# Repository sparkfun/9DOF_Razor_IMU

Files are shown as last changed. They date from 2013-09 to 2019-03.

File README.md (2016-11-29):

SparkFun 9DoF Razor IMU M0
========================================

SparkFun 9DoF Razor IMU M0 (https://www.sparkfun.com/products/14001)

[*SparkFun 9DoF Razor IMU M0 (SEN-14001)*](https://www.sparkfun.com/products/14001)

The [SparkFun 9DoF Razor IMU M0](https://www.sparkfun.com/products/14001) combines a [SAMD21](https://www.sparkfun.com/products/13664) microprocessor with an [MPU-9250](https://www.sparkfun.com/products/13762) 9DoF (nine degrees of freedom) sensor to create a tiny, re-programmable, multi-purpose inertial measurement unit (IMU). It can be programmed to monitor and log motion, transmit Euler angles over a serial port, or to even act as a step-counting pedometer.

The 9DoF Razor's MPU-9250 features three, three-axis sensors -- an accelerometer, gyroscope, and magnetometer -- which gives it the ability to sense linear acceleration, angular rotation velocity, and magnetic field vector's. The on-board microprocessor -- Atmel's [SAMD21G18A](http://www.atmel.com/devices/ATSAMD21G18.aspx) -- is an Arduino-compatible, 32-bit ARM Cortex-M0+ microcontroller also featured on the [Arduino Zero](https://www.arduino.cc/en/Main/ArduinoBoardZero) and [SAMD21 Mini Breakout](https://www.sparkfun.com/products/13664) boards.

Repository Contents
-------------------

* **/Documentation** - Data sheets, additional product information
* **/Firmware** - Example code 
* **/Hardware** - Eagle design files (.brd, .sch)
* **/Libraries** - Libraries for use with the 9DoF Razor IMU M0
* **/Production Files** - Production panel files (.brd)

Documentation
--------------
* **[SparkFun MPU-9250 DMP Arduino Library](https://github.com/sparkfun/SparkFun_MPU-9250-DMP_Arduino_Library)** - Arduino library for the 9DoF Razor IMU M0's MPU-9250, enabling the 9DoF's digital motion processor (DMP).
* **[Hookup Guide](https://learn.sparkfun.com/tutorials/9dof-razor-imu-m0-hookup-guide)** - Basic hookup guide for the 9DoF Razor IMU M0.
* **[SparkFun Fritzing repo](https://github.com/sparkfun/Fritzing_Parts)** - Fritzing diagrams for SparkFun products.
* **[SparkFun 3D Model repo](https://github.com/sparkfun/3D_Models)** - 3D models of SparkFun products. 

Product Versions
----------------
* [SparkFun 9DoF Razor IMU M0 (SEN-14001)](https://www.sparkfun.com/products/14001)- Latest release.
* [SparkFun 9DoF Razor IMU (SEN-10736)](https://www.sparkfun.com/products/retired/10736) - Initial release, featuring an ATmega328, ADXL345 (accelerometer), ITG-3200 (gyroscope), and HMC5883L (magnetometer).

Version History
---------------
* [V_3.0](https://github.com/sparkfun/9DOF_Razor_IMU/releases/tag/V_3.0) - Hardware and firmware files for version 3.0 -- released as SEN-14001.
* [V_2.3](https://github.com/sparkfun/9DOF_Razor_IMU/releases/tag/V_2.3) - Hardware and firmware design files for version 2.3 -- released as SEN-10736.

License Information
-------------------

This product is _**open source**_! 

Please review the LICENSE.md file for license information. 

If you have any questions or concerns on licensing, please contact techsupport@sparkfun.com.

Distributed as-is; no warranty is given.

- Your friends at SparkFun.

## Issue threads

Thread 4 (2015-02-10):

v23 Firmware Crashing on As-Delivered Razor

gdevenyi, 2015-02-10:
I just wired up my razor and turned it on, the menu shows up, and I can interact with it, the magnometer and the gyro work properly (print out measurements), however, if I try and trigger the Accelerometer output, the device crashes:

```
9DOF IMU Firmware v23
==========================
[1]Accelerometer: ADXL345
[2]Magnetometer: HMC5883
[3]Gyroscope: ITG-3200
[4]Raw Output
[5]Change Baud Rate: 57600bps
[Ctrl+z]Toggle Autorun
[?]Help
<PRESSED 1>

x=-22772, y= -28, ITG: GOOD
HMC: GOOD
ADXL: GOOD

9DOF IMU Firmware v23
==========================
[1]Accelerometer: ADXL345
[2]Magnetometer: HMC5883
[3]Gyroscope: ITG-3200
[4]Raw Output
[5]Change Baud Rate: 57600bps
[Ctrl+z]Toggle Autorun
[?]Help
```

This cycle is accompanied by the LEDs doing their "4 blinks and off" for "good"

ToniCorinne, 2015-02-13:
Hey there - sorry to hear about this problem. It sounds like this might be more hardware based, so please contact our tech support team at techsupport@sparkfun.com. They should be able to help you out with the hardware fix easier than we could do on GitHub (and get you a replacement if needed :) ).

gdevenyi, 2015-02-13:
In a email thread with them too. Thanks.

gdevenyi, 2019-02-18:
Defective device replaced.

Closed 2019-02-18.

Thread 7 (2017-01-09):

samd21_sam_ba.atsln file not existing in the repository

lunarpulse, 2017-01-09:
I have tried to compile and learn from the firmware. However, the repository does not have the solution file for Atmel studio. In addition, there are some errors while compiling without the solution file.

First: non existing member of the volatile structures of U

Error		'volatile struct <anonymous>' has no member named 'TRCPT' at 9dof_bootloader_sparkfun\board_driver_usb.c	176	52	Build

Error		'volatile struct <anonymous>' has no member named 'STALLRQ'	\9dof_bootloader_sparkfun\board_driver_usb.c	307	51	Build

Both of them are located in USB_DEVICE_EPINTFLAG_Type struct in usb.h. But the compiler could not find.

I guess these compilation issues may be caused by the absence of the samd21_sam_ba.atsln file or other absent files which contain the right configuration for the compilation.

Furthermore, could you guide me how to correctly compile this in Atmel studio?

lunarpulse, 2017-01-11:
I have investigated a little more and I found out that the USB_DEVICE_EPINTFLAG_Type union contains three fields of structs, bit, vec, and reg. 'TRCPT' and 'STALLRQ' both are member of vec, NOT bit.
the codes was intended to get the status bits stored as a union but the samba_usb.c file did not implement the use of the union struct correctly. I am not sure this was used by arduino zero directly. At least this does not work on atmel and linux arm gcc compiler.

After fixing all the errouneous member indication in the samba_usb.c file, the file compiles but still many errors to correct during the compilation of other files.

santaimpersonator, 2019-07-12:
I don't really have any information beyond what is listed here (I primarily do minor TS):
https://github.com/sparkfun/9DOF_Razor_IMU/tree/master/Firmware/Bootloader

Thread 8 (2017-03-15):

Compass heading wrong values

theonteg, 2017-03-15:
Compass heading values are not responding to reality in RAZOR IMU M0.
A full circle around z axis is changing heading values between 250 and 360 only... (should change respectively with the yaw value but it is not)

santaimpersonator, 2019-03-14:
As described in this [blog post](https://www.sparkfun.com/news/2814), the magnetometer isn't the "_star of the show_" and you may want to look at seperate magnetometer. The magnetometer also isn't tilt compensated by default (with the example firmware code).

Closed 2019-03-14.

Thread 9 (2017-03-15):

Roll, Pitch, Yaw values changing counterintuitive

theonteg, 2017-03-15:
I have two issues with the Roll, Pitch, Yaw values returned from the RAZOR IMU M0.

1. Yaw values are different every time the IMU turns on.
Depending on the heading of the IMU the time it turns on the yaw 0 value "snaps" on the closest cardinal point.

2. Roll and Pitch values interchange depending the Yaw value.
Turning the IMU around it's Y mag axis while Yaw is 0, changes the Roll value
Turning the IMU around it's Y mag axis while Yaw is 90, changes the Pitch value

Are those two issues normal? Because they are counterintuitive to me...

dahlsrud, 2017-03-16:
1. My experience is the same. I am not activating the  magnetic compass, so in that case the IMU does not have a fixed reference point for Yaw and just initializes it during startup to wherever it is pointing. The gyros can only detect relative movement, and the accelerometers can't detect Yaw. I guess the IMU *could* fix Yaw towards magnetic north at startup, but during testing I have never achieved that. For Pitch and Roll it is different, because the IMU can easily fix them to the horizontal plane by looking at the accelerometer and determining the direction of gravity.
If you want a fixed Yaw from every boot I guess you must add some extra code yourself by calculating the magnetic compass heading and compensating gyro Yaw against that. But I'd like to know more info about that myself.

2. In my understanding, this is a bug. Wikipedia has another formula for calculating Euler from Quaternions which works as expected:
https://en.wikipedia.org/wiki/Conversion_between_quaternions_and_Euler_angles

theonteg, 2017-03-16:
1. Does enabled mag log means that it is enabled?
I was hoping to avoid writing my own code for solving this (so that the solution is merged to the official firmware) but I will try.

2. Used this (Wikipedia's) approach yesterday but I have one problem. Pitch in some directions freezes at 90 degrees no matter the movement. I don't believe that there is something wrong with the code but I will check it thoroughly this weekend.

dahlsrud, 2017-03-16:
1. I never worked with it, but I suppose so yes.
I fear that we are lacking a good calibration code for the compass and that it involves having to rotate the IMU physically in 8-circles to gather calibration values for the earth magnetism in a given location.

Btw, the current original firmware also contains a bug which multiplies Pitch with 2 erroneously.

2. I posted working firmware code in this thread:
https://forum.sparkfun.com/viewtopic.php?f=14&t=45516
It contains its own routine to convert Quaternions to Euler angles. It is working great for me.
You might have to modify the output format for your needs, though.

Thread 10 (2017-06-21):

Gyro fails to calibrate

mushroomRetainer, 2017-06-21:
Using this firmware, it seems the gyro introduces a significant drift into the roll, pitch, and yaw measurements (about 1 degree/second). I found that this can be fixed by changing this section of the code:

if (ENABLE_GYRO_CALIBRATION)
  {
    // Gyro calibration re-calibrates the gyro after a set amount
    // of no motion detected
    dmpFeatureMask |= DMP_FEATURE_SEND_CAL_GYRO;
  }

and replacing it with the following:

if (ENABLE_GYRO_CALIBRATION)
{
    // Gyro calibration re-calibrates the gyro after a set amount
    // of no motion detected
    dmpFeatureMask |= DMP_FEATURE_GYRO_CAL; //added this line
    dmpFeatureMask |= DMP_FEATURE_SEND_CAL_GYRO;
}

This way the gyro calibrates after 8 seconds of no movement from the accelerometer. I can't think of a situation in which you wouldn't want this feature turned on.

santaimpersonator, 2019-03-14:
Oops, looks like we might have missed that. Thanks for the heads up.

You are correct as mention here:
https://github.com/sparkfun/9DOF_Razor_IMU/blob/master/Libraries/Arduino/src/util/inv_mpu_dmp_motion_driver.c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

I have updated the firmware code in the repository to reflect this. I will update the hookup guide as well.

Closed 2019-03-14.

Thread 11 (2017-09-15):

Wrong temperature output.

dyqi, 2017-09-15:
From document <<MPU-9250-Register-Map.pdf>>, there is  information below:
"
        TEMP_degC = ((TEMP_OUT – RoomTemp_Offset)/Temp_Sensitivity)+ 21degC
        Where Temp_degC is the temperature in degrees C measured by the temperature sensor.
        TEMP_OUT is the actual output of the temperature sensor.
"

    mpu_get_temperature function in "inv_mpu.c" file give a wrong temperature value, codes is below:
"
        data[0] = (long)((35 + ((raw - (float)st.hw->temp_offset) / st.hw->temp_sens)) * 65536L);
"

Why is there a "35" here ? It should be a bug.

santaimpersonator, 2019-03-14:
I am not sure where you are getting this error:

> mpu_get_temperature function in "inv_mpu.c" file give a wrong temperature value, codes is below:

However, I believe that the 35 is for the **21degC** indicated by the register map. For further technical assistance with this product, please use our [forums](https://forum.sparkfun.com/index.php).

Closed 2019-03-14.

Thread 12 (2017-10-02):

Can't read or write in Linux

danmartinez78, 2017-10-02:
The board shows up as /dev/ttyACM0 but cannot be read from or written to. Arduino IDE in Linux hangs on writing data in serial monitor. The board works fine in windows.

kruftindustries, 2017-12-21:
sudo chmod 777 /dev/ttyACM0

Look up how to put it in your upstart rules if you want the permission settings to survive a restart

bboyho, 2018-08-17:
Hi,

If the board works with a Windows but not on a Linux, it may be due to your permissions as kruftindustries stated. I am not sure what version of the Arduino IDE you are using. Try reinstalling the Arduino IDE or using a different version if you have not already. Looking briefly at the Arduino.cc forums and StackExchange: Arduino, this can also help when data "freezes" or "hangs" as data is sent to the Arduino serial monitor.

Since there has not been a response, I assume that the issue was resolved. We can re-open this issue if you are still having problems.

PS: Thanks @kruftindustries for posting! =)

Closed 2018-08-17.

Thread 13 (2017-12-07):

Does the ROS driver razor_imu_9dof work for this model?

tony1098, 2017-12-07:
The razor_imu_9dof (http://wiki.ros.org/razor_imu_9dof) only mentions that it supports SEN-10736 and SEN-10125. Does it support this model as well?

lebarsfa, 2018-04-04:
Some support has been recently added for the M0 but using a modified firmware, see https://github.com/KristofRobot/razor_imu_9dof

improve100, 2018-04-10:
yes

santaimpersonator, 2019-03-14:
Unfortunately, I am not absolutely sure since the [SEN-10736](https://www.sparkfun.com/products/retired/10736) used completely different sensors than the MPU-9250 IMU. However, the resource [https://github.com/KristofRobot/razor_imu_9dof](https://github.com/KristofRobot/razor_imu_9dof) linked by [lebarsfa](https://github.com/lebarsfa) seems to indicate it is.

For further assistance, I will need to redirect you to the contact information on that wiki page:

> **Maintainer: Kristof Robot <krirobo AT gmail DOT com>**

who is probably better suited to answer further questions regarding their code.

Closed 2019-03-14.

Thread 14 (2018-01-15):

SPI pins of Razor imu m0

Thzn, 2018-01-15:
Hi,
Anyone know the correct SPI pinouts of the razor imu mo. In the website they said that 10-13 can be used for SPI communication. Can anyone explain it further. What are the mappings of MISO, MOSI, SCK, and SS to those pins (what is the order.....)
Thank you.

bboyho, 2018-08-17:
Hi,

It looks like most of those pins are defined in these files:

[https://github.com/sparkfun/Arduino_Boards/blob/master/sparkfun/samd/variants/SparkFun_9DoF_M0/variant.cpp#L58](https://github.com/sparkfun/Arduino_Boards/blob/master/sparkfun/samd/variants/SparkFun_9DoF_M0/variant.cpp#L58)

,

[https://github.com/sparkfun/Arduino_Boards/blob/master/sparkfun/samd/variants/SparkFun_9DoF_M0/variant.h#L130](https://github.com/sparkfun/Arduino_Boards/blob/master/sparkfun/samd/variants/SparkFun_9DoF_M0/variant.h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)

, and

[https://github.com/sparkfun/9DOF_Razor_IMU/blob/2865253ffa7e31ac77c2e741931da7af4e8779a4/Firmware/_9DoF_Razor_M0_Firmware/config.h](https://github.com/sparkfun/9DOF_Razor_IMU/blob/2865253ffa7e31ac77c2e741931da7af4e8779a4/Firmware/_9DoF_Razor_M0_Firmware/config.h)

Looking at the Eagle files, the pins are not broken out to a through hole by default. However, it is connected to the microSD card socket.

You should be able to create a new instance by assigning pins 10-13 to SPI. I have not tested this out before so I do not know the exact details of how to do this. While this was written for making another UART instance on the MKR1000, this may give you some insight in how to do this for SPI on the 9DoF => [https://www.arduino.cc/en/Tutorial/SamdSercom](https://www.arduino.cc/en/Tutorial/SamdSercom) ]. Also, try looking at this Arduino.cc Forum post for an idea => [ [https://forum.arduino.cc/index.php?topic=500381.msg3413461#msg3413461](https://forum.arduino.cc/index.php?topic=500381.msg3413461#msg3413461) ].

Closed 2018-08-17.

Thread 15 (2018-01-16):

SPI pin for IMU M0

Manujaya94, 2018-01-16:
I have an  issue when runing the  Arduino -SPI library for IMU M0. Because in the datasheet there are no reference to identify SPI pins. Therefore can you help us to identify which pins are referenced for SPI protocol.

bboyho, 2018-08-17:
Hi,

Try looking at my comment here for details => [https://github.com/sparkfun/9DOF_Razor_IMU/issues/14#issuecomment-413958078](https://github.com/sparkfun/9DOF_Razor_IMU/issues/14#issuecomment-413958078) .

Closed 2018-08-17.

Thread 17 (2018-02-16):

IMU does not detect in COM port

dibs06, 2018-02-16:
I have 2 Sparkfun MPU9250 ,first is connected with the arduino by itc I2C pin ,another one is connected with my PC via USB
Accidently I had upload Sparkfun MPU 9250 breakout program (which is connect with i2c in arduino) into the Saprkfun with DMP IMU(which is connect with the PC via USB).
Just after that it cannot detect in COM port.
What should I do?

bboyho, 2018-08-17:
Hi,

If you are not able to see the 9DoF Razor IMU M0 anymore in your device manager, you can try to set it back by putting it in bootloader mode.  With any AVR device that has a built in CDC (i.e. the Atmega32U4 bootloaded with Arduino on the Pro Micro, FioV3, LilyPad Arduino USB, etc), there should be an option to place the board into bootloader mode if you brick the board. Try following the “Troubleshooting” note listed in the tutorial [ [https://learn.sparkfun.com/tutorials/9dof-razor-imu-m0-hookup-guide/all#installing-the-9dof-razor-arduino-core](https://learn.sparkfun.com/tutorials/9dof-razor-imu-m0-hookup-guide/all#installing-the-9dof-razor-arduino-core) ]:

> If your 9DoF Razor IMU won’t enter the bootloader, or take new code, you can force it into the bootloader by holding the SCL pin LOW on start up. Flip the IMU’s switch off, use a jumper wire to connect SCL to GND, and turn the switch back on. While in the bootloader, the blue pin 13 LED should remain illuminated.

You should then be able to upload the firmware [ [https://github.com/sparkfun/9DOF_Razor_IMU/blob/master/Firmware/_9DoF_Razor_M0_Firmware/_9DoF_Razor_M0_Firmware.ino]()https://github.com/sparkfun/9DOF_Razor_IMU/blob/master/Firmware/_9DoF_Razor_M0_Firmware/_9DoF_Razor_M0_Firmware.ino ] back to the SAMD21

Closed 2018-08-17.

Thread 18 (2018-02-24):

Serial Output does not work

rickblair, 2018-02-24:
When I initially received the unit, it worked with only the USB connected.  I hooked another device to the VCC GRND Rx and TX breakout pins to receive serial output.  Now the IMU fails in during loop in the call:  if ( imu.dmpUpdateFifo() != INV_SUCCESS )

I also cannot log to the LOG_PORT.  LOG_PORT.println("foo") does not produce any output.   I debugged the programs progress using the Blue LED.

So several questions.  What are the Tx Rx breakout pins?  Is it Serial1
Seems like IMU is disabled somehow?  What to do to reenable?

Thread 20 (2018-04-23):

dmpGetPedometerSteps values

gretamosa, 2018-04-23:
I am using MPU9250_DMP_Pedometer example with Adafruit Feather M0.

Once compiled and uploaded the example into the board, I noticed that the walks number and their refresh interval into the serial monitor is so slow and I am not pretty sure that precise.

Anybody can help me? is it necessary calibrate the MPU9250 before or something like that?

Thanks in advanced,

santaimpersonator, 2019-03-15:
Seeing as this is the repository for the SparkFun Razor IMU board, this issue might be better suited for the [DMP library](https://github.com/sparkfun/SparkFun_MPU-9250-DMP_Arduino_Library).

That being said, make sure your hardware is set up properly for the Feather first. I tested the sketch and it seems to work fine on the SparkFun Razor IMU. From my testing, the sketch only outputs serial data when it registers steps. From experimenting, it looks like it needs some exaggerated strides to work (I had to jump up and down quite a few times. I found the sweet spot to be about 12-16" movements vertically at half-second intervals).

Unfortunately, I don't have a lot of insight into the pedometer feature as it is dependent on the DMP from Invensense and most of that code is "*black box"*.

Closed 2019-03-15.

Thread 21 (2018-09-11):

Adding analog input to Logs

albertofast, 2018-09-11:
Dear all,
I bought the Sparkfun Razor imu m0 to compare its results with an industrial optical motion tracking system ( double integration to extract trajectory plus euler angles). The IMU will be used on a model falling in the air from about 3m height and then impacting on the water. I would like to add to my logs an analog input: a voltage signal ranging from 0 to 5v, sampled @100Hz like the rest of the imu data. As I am totally new to arduino  I kindly ask you a suggestion of how and where to modify the code to add the voltage read to the log file data output and to the serial monitor.
Thank you!

santaimpersonator, 2019-03-14:
Please refer to this [Arduino Analog Input Reference Page](https://www.arduino.cc/en/tutorial/AnalogInput). For further technical assistance with our products, please head over to our [forums](https://forum.sparkfun.com/index.php).

Closed 2019-03-14.

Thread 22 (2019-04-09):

Increase the frequency more than 100 Hz

arkinrc, 2019-04-09:
Hello everybody,
   I am working on this new Razor Imu M0 with SN14001. I want to use the sampling frequency around 200 hz and i tried many ways to change it however, more than 100 hz always got some errors on ros. i would strongly appreciate if someone have already solved this issue.  thanks .

santaimpersonator, 2019-07-12:
Check out this issue, the user ended up increasing the speed on the I2C bus:

https://github.com/sparkfun/SparkFun_MPU-9250-DMP_Arduino_Library/issues/12

arkinrc, 2019-07-17:
Hi @santaimpersonator ok. thanks...

Closed 2019-07-17.

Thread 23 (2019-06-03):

I2C scan

MigSanc, 2019-06-03:
Dear all,

Recently I have acquired a 9DOF_Razor_IMU. I am currently trying to scan the i2c to check the addresses of the MPU9250, but if a run the i2c scanner the arduino does not print any addresses found. Does anybody know how can I scan the i2c from the 14001 9DOF_Razor_IMU board?

Best regards,
Miguel

santaimpersonator, 2019-07-12:
Hi there, it sounds like you are looking for [technical assistance](https://www.sparkfun.com/technical_assistance). Please use the link, to get started with posting a topic in our [forums](https://forum.sparkfun.com/). Our technical support team will do their best to assist you.

In your forum post, it would probably help the TS team if you include a picture of your setup of how you have everything wired for the I2C scan.

Closed 2019-07-12.

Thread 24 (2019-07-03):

Wire.requestFrom() should not be followed by Wire.endTransmission().

Koepel, 2019-07-03:
In the file "9DOF_Razor_IMU/Libraries/Arduino/src/util/arduino_mpu9250_i2c.cpp", in the function "arduino_i2c_read()", there is a `Wire.endTransmission()` after a `Wire.requestFrom()`.

That `Wire.endTransmission()` is at the moment here: https://github.com/sparkfun/9DOF_Razor_IMU/blob/master/Libraries/Arduino/src/util/arduino_mpu9250_i2c.cpp#L46 and can be removed.

Explanation: [Common-mistakes#2](https://github.com/Koepel/How-to-use-the-Arduino-Wire-library/wiki/Common-mistakes#2)

santaimpersonator, 2019-07-12:
I am going to close this issue as the library used for the Arduino IDE actually lives here:

https://github.com/sparkfun/SparkFun_MPU-9250-DMP_Arduino_Library

and the `Wire.endTransmission()` issue has already been taken care of.

Closed 2019-07-12.

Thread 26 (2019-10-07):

IMU I2C address should be breakout

LucaCerina, 2019-10-07:
Hello,
I wanted to use the sparkfun Razor to record long-term accelerations. However, the default I2C address is 0x68 which conflicts with almost every decent I2C Real-Time Clock on the market.

I suggest that the default address should be changed to 0x69 or exposed with a small port on the breakout to be changed manually

improve100, 2019-10-07:
i have the board that you want.

---Original---
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

LucaCerina, 2019-10-07:
which one?
Luca Cerina
----------------
Graduate Research Assistant @ NECSTLab
DEIB (Dipartimento di Elettronica, Informazione e Bioingegneria)
Politecnico di Milano

Il giorno lun 7 ott 2019 alle ore 11:24 improve100 <notifications@github.com<mailto:notifications@github.com>> ha scritto:
i have the board that you want.

---Original---
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

LucaCerina, 2019-10-07:
Of course I can rewire the circuit, but I would like to avoid the process on multiple samples just to have something that could be already available with an exposed soldering pad or something like that

improve100, 2019-10-07:
i think you can jump wire.or buy the board that you want

---Original---
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

nseidle, 2019-10-07:
OP - good point. We should have broken out the I2C address pin to a jumper or GPIO so that the user could change the IMU address. Unfortunately it's hard wired to 0x68. We'll try to fix this on a future rev.

As an aside, the SAMD21 is clocked with a 32.768kHz xtal. You may be able to setup an RTC function directly on the micro without the need for an external RTC.

LucaCerina, 2019-10-08:
Fair enough, I will try also with that and see if the drift is ok.

Closed 2019-10-08.

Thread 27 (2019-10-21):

Not reading serial data if booting with SBC

msadowski, 2019-10-21:
Hi!

I have a weird issue that I've seen in two separate firmwares for this IMU board. What I'm observing is that if I connect the IMU to my USB port while the SBC is running everything seems to work well - I can read data, and with the default .ino sending a space character stops the stream (1).

If however I have the IMU plugged in to the SBC when I power up the SBC I read the IMU data just fine but I can't send anything to the board (2).

When debugging I was printing the serial available bytes (LOG_PORT.available()) in case 1 as I was sending characters I could see that available() bytes on the log port increased. In case of 2nd configuration the LOG_PORT.available() always returned 0.

Did anyone run into this? Any tips on how to approach this problem?

msadowski, 2019-10-22:
As a follow up test I've tested this with a trivial sketch that reads serial data and sends it back. I can confirm that this issue is also visible in this case:

```
int incomingByte = 0;    // for incoming serial data

void setup() {
    SerialUSB.begin(9600);    // opens serial port, sets data rate to 9600 bps
}

void loop() {
  // send data only when you receive data:
  if (SerialUSB.available() > 0) {

    // read the incoming byte:
    incomingByte = SerialUSB.read();

    // say what you got:
    SerialUSB.print((char)incomingByte);
  }

}
```

santaimpersonator, 2020-10-08:
What does SBC represent?

I've used the Razor on multiple computers and I've never had an issue retrieving data or controlling it from a serial terminal (emulator) after the computer boots. Have you tried debugging whatever the SBC is?

msadowski, 2020-10-09:
SBC is "Single Board Computer" in this context. Basically any time I was powering the machine with the board already plugged in I was having issues.

santaimpersonator, 2020-10-09:
I have never had any issues with the Razor working on a Raspberry Pi from boot up. However, I have never really been trying to control it through the serial (USB) connection. I was mostly testing it out as a VR headset concept:
https://www.sparkfun.com/news/2882

Maybe it is a kernel/application specific issue communicating with the USB device? I have found screen to work consistently, don't forget to check your baud rate... I've seen some emulators display properly at double/quadruple the baud rate.
Since you are using an SBC... have you tried just connecting it to the serial pins directly?

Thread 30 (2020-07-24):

Mechanical Drawing

zshivers, 2020-07-24:
Can you provide a drawing for the overall dimensions, hole dimensions, and the IMU location / orientation? While this info is probably available within the eagle PCB files, it would be much more convenient for your users to publish as a PDF.

santaimpersonator, 2020-10-08:
Unfortunately, this product has since been retired: https://www.sparkfun.com/products/retired/14001

Going forward, we are making an effort to publish dimensions for new boards. I will be closing this issue since users can download and look at the Eagle files.

Closed 2020-10-08.

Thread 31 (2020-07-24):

How to get higher number of digits using Arduino library?

hurak, 2020-07-24:
Hi, trying the [MPU9250_Basic](https://github.com/sparkfun/9DOF_Razor_IMU/blob/master/Libraries/Arduino/examples/MPU9250_Basic/MPU9250_Basic.ino) example from the Arduino library, I can see (using the serial port monitor) that the measurements are sent from the unit with just four or even three digits of precision. Both the accelerometer and the magnetometer on MPU 9250 have 16-bit ADCs, which means that with the accelerometer returning values such as 1.23, the precision was unnecessarily significantly reduced, was not it? Is it possible to configure the library functions such that higher number of digits can be read from the IMU? Thanks.

santaimpersonator, 2020-10-08:
Hi there, it sounds like you are looking for [technical assistance](https://www.sparkfun.com/technical_assistance). Please use the link, to get started with posting a topic in our [forums](https://forum.sparkfun.com/). Our technical support team will do their best to assist you.

That being said, please refer to the [documentation for the String function](https://www.arduino.cc/reference/en/language/variables/data-types/stringobject/).

As this doesn't seem to be an issue in the code, I will be closing it.

Closed 2020-10-08.

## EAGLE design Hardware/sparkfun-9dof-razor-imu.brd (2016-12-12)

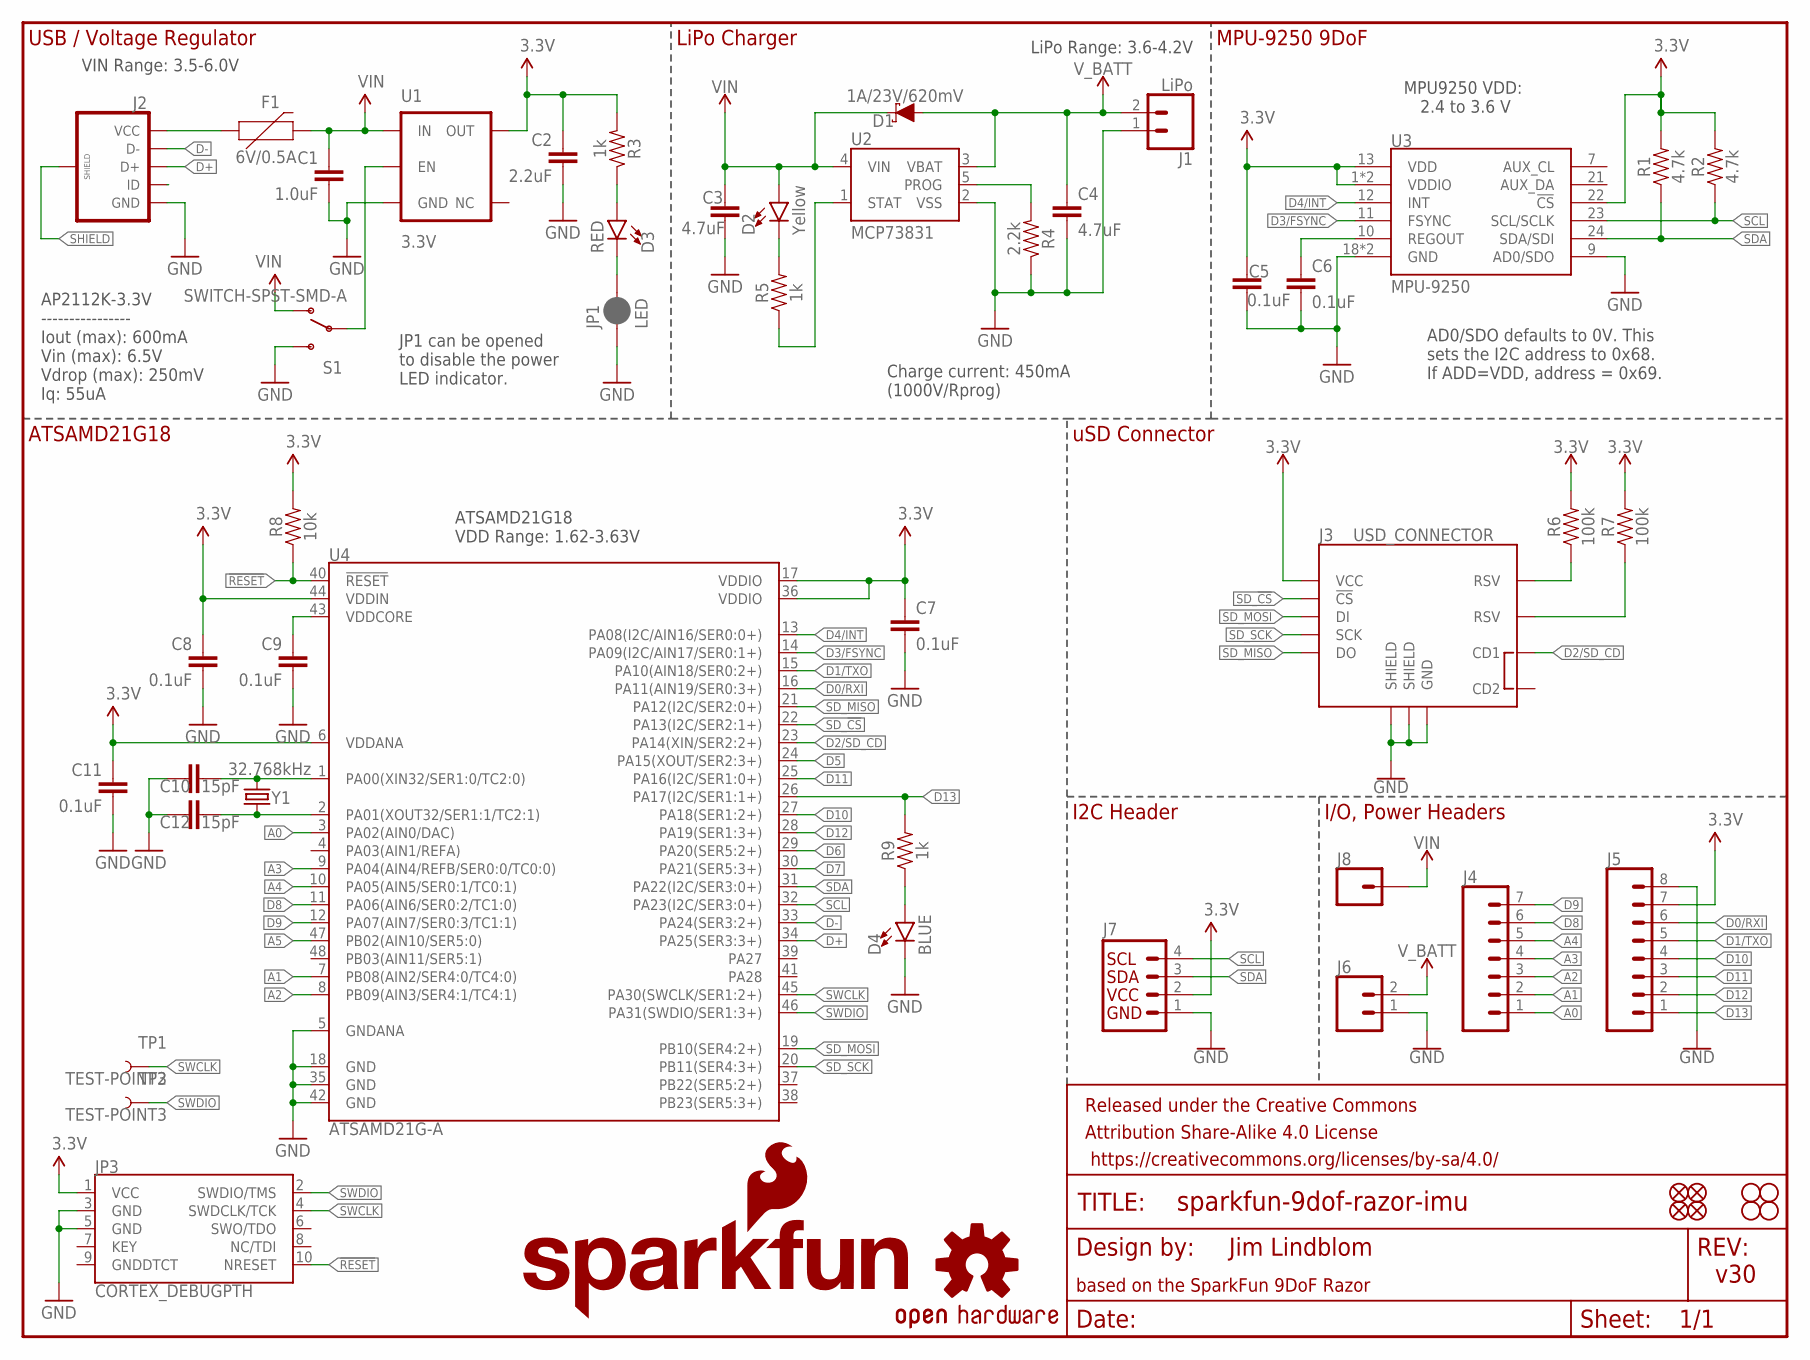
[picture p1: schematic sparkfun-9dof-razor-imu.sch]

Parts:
C1: 1.0uF; 0603
C2: 2.2uF; 0603
C3, C4: 4.7uF; 0603
C5, C6, C7, C8, C9, C11: 0.1uF; 0603
C10, C12: 15pF; 0603
D1: 1A/23V/620mV; SOD-323
D2: Yellow; LED-0603
D3: RED; LED-0603
D4: BLUE; LED-0603
F1: 6V/0.5A; 1206
FD1, FD2, FD3, FD4: FIDUCIAL1X2; FIDUCIAL-1X2
FRAME1: FRAME-LETTER; CREATIVE_COMMONS
H1, H2, H3, H4: STAND-OFF
J1: LiPo; JST-2-SMD
J2: USB_MICROB_PLUGCONN-11752; USB-B-MICRO-SMD_V03
J3: USD_CONNECTOR; MICRO-SD-SOCKET-PP
J4: CONN_07; 1X07
J5: CONN_08"; 1X08
J6: CONN_02; 1X02
J7: I2C_STANDARD; 1X04
J8: CONN_01; 1X01
JP1: LED; SMT-JUMPER_2_NC_PASTE_NO-SILK
JP3: CORTEX_DEBUGPTH; 2X5-PTH-1.27MM
LOGO1: SFE_LOGO_FLAME.1_INCH; SFE_LOGO_FLAME_.1
LOGO2: OSHW-LOGOS; OSHW-LOGO-S
LOGO3: SFE_LOGO_NAME.1_INCH; SFE_LOGO_NAME_.1
R1, R2: 4.7k; 0603
R3, R5, R9: 1k; 0603
R4: 2.2k; 0603
R6, R7: 100k; 0603
R8: 10k; 0603
S1: SWITCH-SPST-SMD-A
TP1, TP2: TEST-POINT3; PAD.03X.03
U1: 3.3V; SOT23-5
U2: MCP73831; SOT23-5
U3: MPU-9250; QFN24-3X3
U4: ATSAMD21G-A; TQFP-48
Y1: 32.768kHz; CRYSTAL-SMD-3.2X1.5MM

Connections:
3.3V: C2.1, C5.1, C7.1, C8.1, C11.1, J3.VCC, J5.7, J7.2, JP3.1 (VCC), R1.2, R2.2, R3.2, R6.2, R7.2, R8.2, U1.5 (OUT), U3.1 (VDDIO), U3.8 (VDDIO), U3.13 (VDD), U3.22 (!CS), U4.6 (VDDANA), U4.17 (VDDIO), U4.36 (VDDIO), U4.44 (VDDIN)
!RESET: JP3.10 (NRESET), R8.1, U4.40 (!RESET!)
A0: J4.1, U4.3 (PA02(AIN0/DAC))
A1: J4.2, U4.7 (PB08(AIN2/SER4:0/TC4:0))
A2: J4.3, U4.8 (PB09(AIN3/SER4:1/TC4:1))
A3: J4.4, U4.9 (PA04(AIN4/REFB/SER0:0/TC0:0))
A4: J4.5, U4.10 (PA05(AIN5/SER0:1/TC0:1))
A5: U4.47 (PB02(AIN10/SER5:0))
CHG_LED: R5.1, U2.1 (STAT)
D0/RXI: J5.6, U4.16 (PA11(AIN19/SER0:3+))
D1/TXO: J5.5, U4.15 (PA10(AIN18/SER0:2+))
D2/SD_CD: J3.CD1, U4.23 (PA14(XIN/SER2:2+))
D3/FSYNC: U3.11 (FSYNC), U4.14 (PA09(I2C/AIN17/SER0:1+))
D4/INT: U3.12 (INT), U4.13 (PA08(I2C/AIN16/SER0:0+))
D5: U4.24 (PA15(XOUT/SER2:3+))
D6: U4.29 (PA20(SER5:2+))
D7: U4.30 (PA21(SER5:3+))
D8: J4.6, U4.11 (PA06(AIN6/SER0:2/TC1:0))
D9: J4.7, U4.12 (PA07(AIN7/SER0:3/TC1:1))
D10: J5.4, U4.27 (PA18(SER1:2+))
D11: J5.3, U4.25 (PA16(I2C/SER1:0+))
D12: J5.2, U4.28 (PA19(SER1:3+))
D13: J5.1, R9.2, U4.26 (PA17(I2C/SER1:1+))
D+: J2.D+, U4.34 (PA25(SER3:3+))
D-: J2.D-, U4.33 (PA24(SER3:2+))
GND: C1.2, C2.2, C3.2, C4.2, C5.2, C6.2, C7.2, C8.2, C9.2, C10.1, C11.2, C12.2, D4.C, J1.1 (2), J2.GND, J3.GND, J3.GND1 (SHIELD), J3.GND3 (SHIELD), J5.8, J6.1, J7.1, JP1.1, JP3.3 (GND), JP3.5 (GND), R4.1, S1.3 (S), U1.2 (GND), U2.2 (VSS), U3.9 (AD0/SDO), U3.18 (GND), U3.20 (GND), U4.5 (GNDANA), U4.18 (GND), U4.35 (GND), U4.42 (GND)
ID: J2.ID
unnamed: F1.1, J2.VBUS (VCC)
unnamed: C10.2, U4.1 (PA00(XIN32/SER1:0/TC2:0)), Y1.P$2 (2)
unnamed: D4.A, R9.1
unnamed: C12.1, U4.2 (PA01(XOUT32/SER1:1/TC2:1)), Y1.P$1 (1)
unnamed: D3.A, R3.1
unnamed: R4.2, U2.5 (PROG)
unnamed: J3.RSV1 (RSV), R6.1
unnamed: J3.RSV2 (RSV), R7.1
unnamed: D2.C, R5.2
unnamed: D3.C, JP1.2
REGOUT: C6.1, U3.10 (REGOUT)
SCL: J7.4, R2.1, U3.23 (SCL/SCLK), U4.32 (PA23(I2C/SER3:0+))
SDA: J7.3, R1.1, U3.24 (SDA/SDI), U4.31 (PA22(I2C/SER3:0+))
SD_!CS!: J3.CS (!CS), U4.22 (PA13(I2C/SER2:1+))
SD_MISO: J3.DO, U4.21 (PA12(I2C/SER2:0+))
SD_MOSI: J3.DI, U4.19 (PB10(SER4:2+))
SD_SCK: J3.SCLK (SCK), U4.20 (PB11(SER4:3+))
SHIELD: J2.SHIELD1 (SHIELD), J2.SHIELD2 (SHIELD), J2.SHIELD3 (SHIELD)
SWCLK: JP3.4 (SWDCLK/TCK), TP1.P$1, U4.45 (PA30(SWCLK/SER1:2+))
SWDIO: JP3.2 (SWDIO/TMS), TP2.P$1, U4.46 (PA31(SWDIO/SER1:3+))
VDDCORE: C9.1, U4.43 (VDDCORE)
VIN: C1.1, C3.1, D1.C, D2.A, F1.2, J8.1, S1.1 (O), U1.1 (IN), U2.4 (VIN)
VREG_EN: S1.2, U1.3 (EN)
V_BATT: C4.1, D1.A, J1.2 (1), J6.2, U2.3 (VBAT)

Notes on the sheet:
AD0/SDO defaults to 0V. This sets the I2C address to 0x68. If ADD=VDD, address = 0x69.
MPU9250 VDD: 2.4 to 3.6 V
USB / Voltage Regulator
ATSAMD21G18 VDD Range: 1.62-3.63V
VIN Range: 3.5-6.0V
AP2112K-3.3V ---------------- Iout (max): 600mA Vin (max): 6.5V Vdrop (max): 250mV Iq: 55uA
v30
Jim Lindblom
ATSAMD21G18
LiPo Charger
MPU-9250 9DoF
uSD Connector
I2C Header
I/O, Power Headers
JP1 can be opened to disable the power LED indicator.
based on the SparkFun 9DoF Razor
LiPo Range: 3.6-4.2V
Charge current: 450mA (1000V/Rprog)

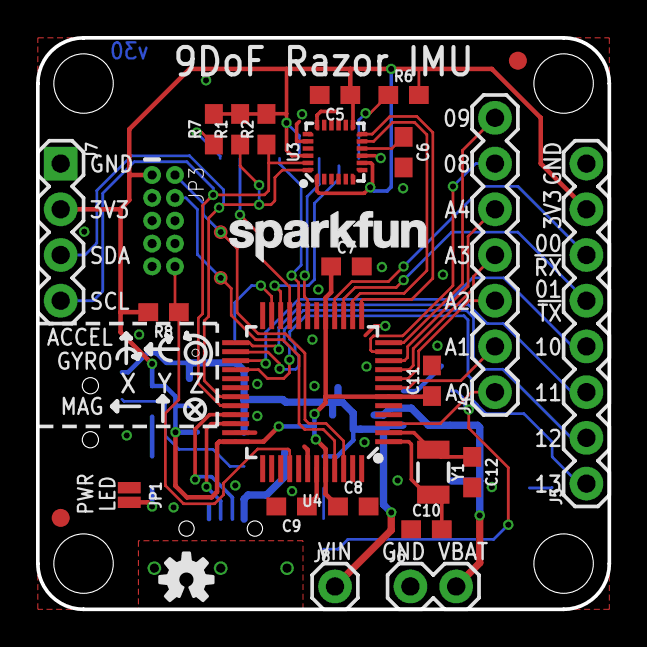
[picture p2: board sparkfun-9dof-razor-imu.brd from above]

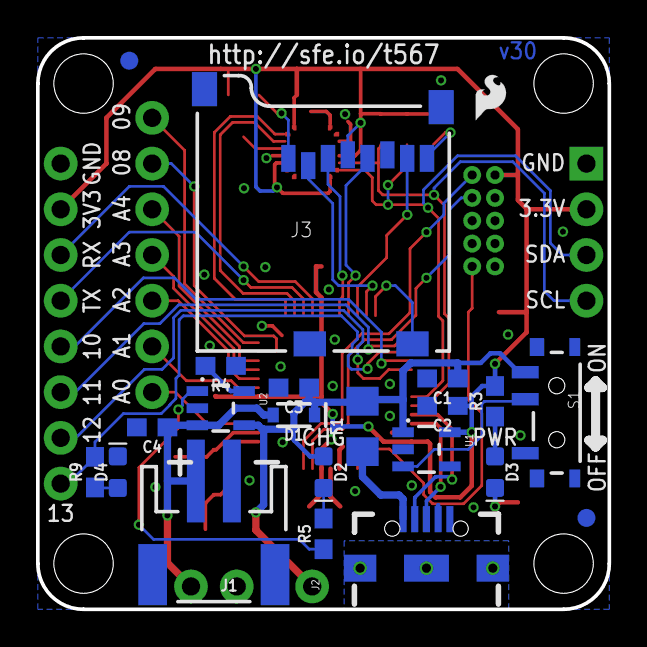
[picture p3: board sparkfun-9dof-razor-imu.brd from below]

Board: 2 copper layers, 31.8 x 31.8 mm, 56 parts (22 on the bottom side), 46 nets.

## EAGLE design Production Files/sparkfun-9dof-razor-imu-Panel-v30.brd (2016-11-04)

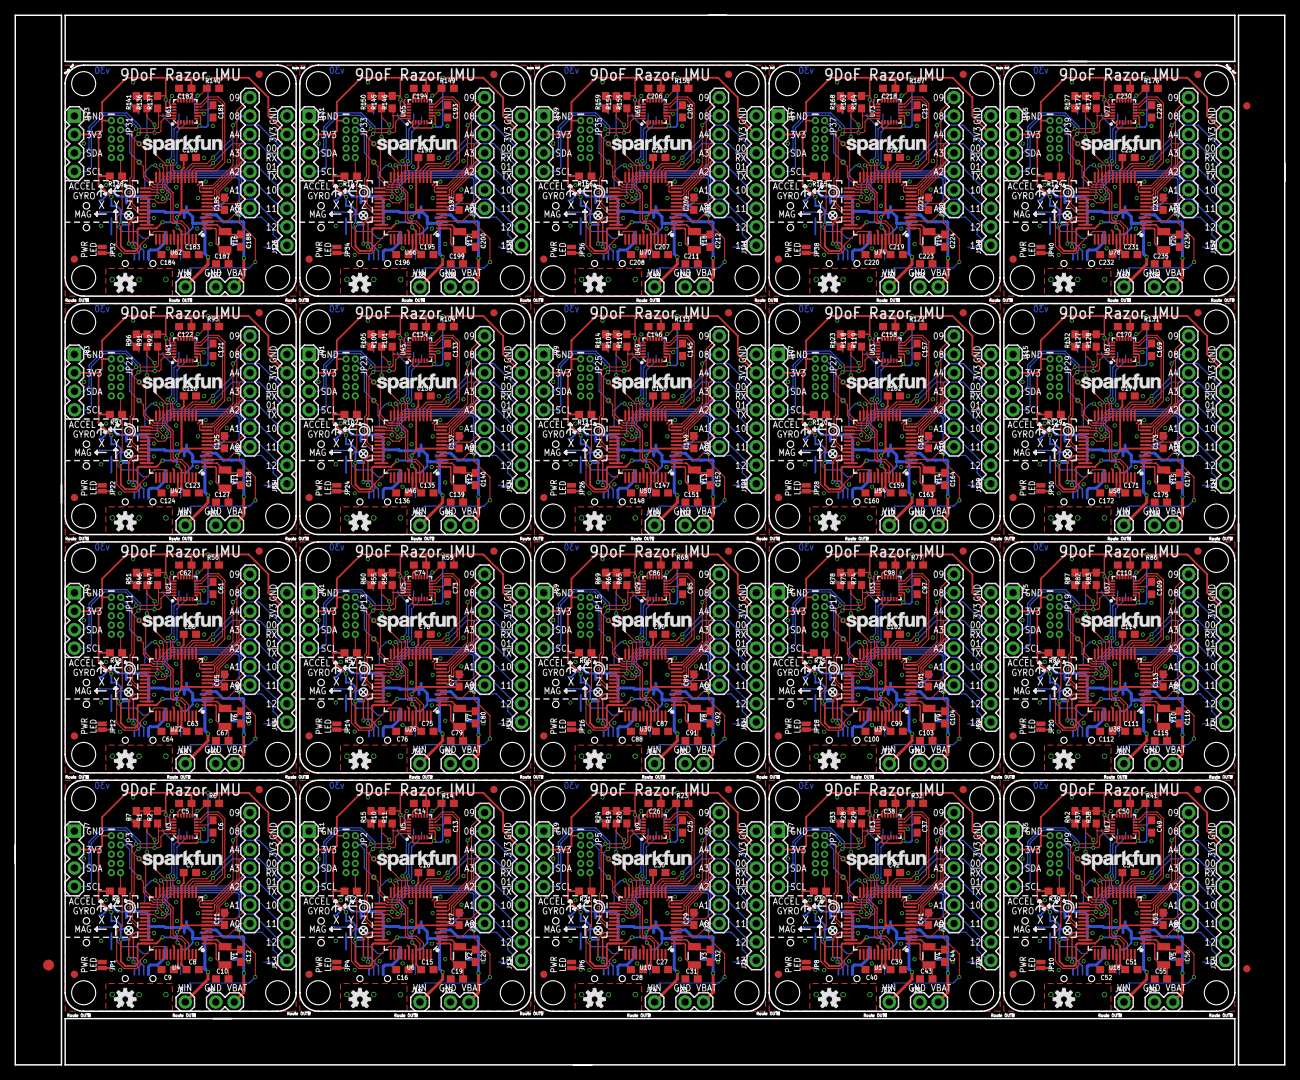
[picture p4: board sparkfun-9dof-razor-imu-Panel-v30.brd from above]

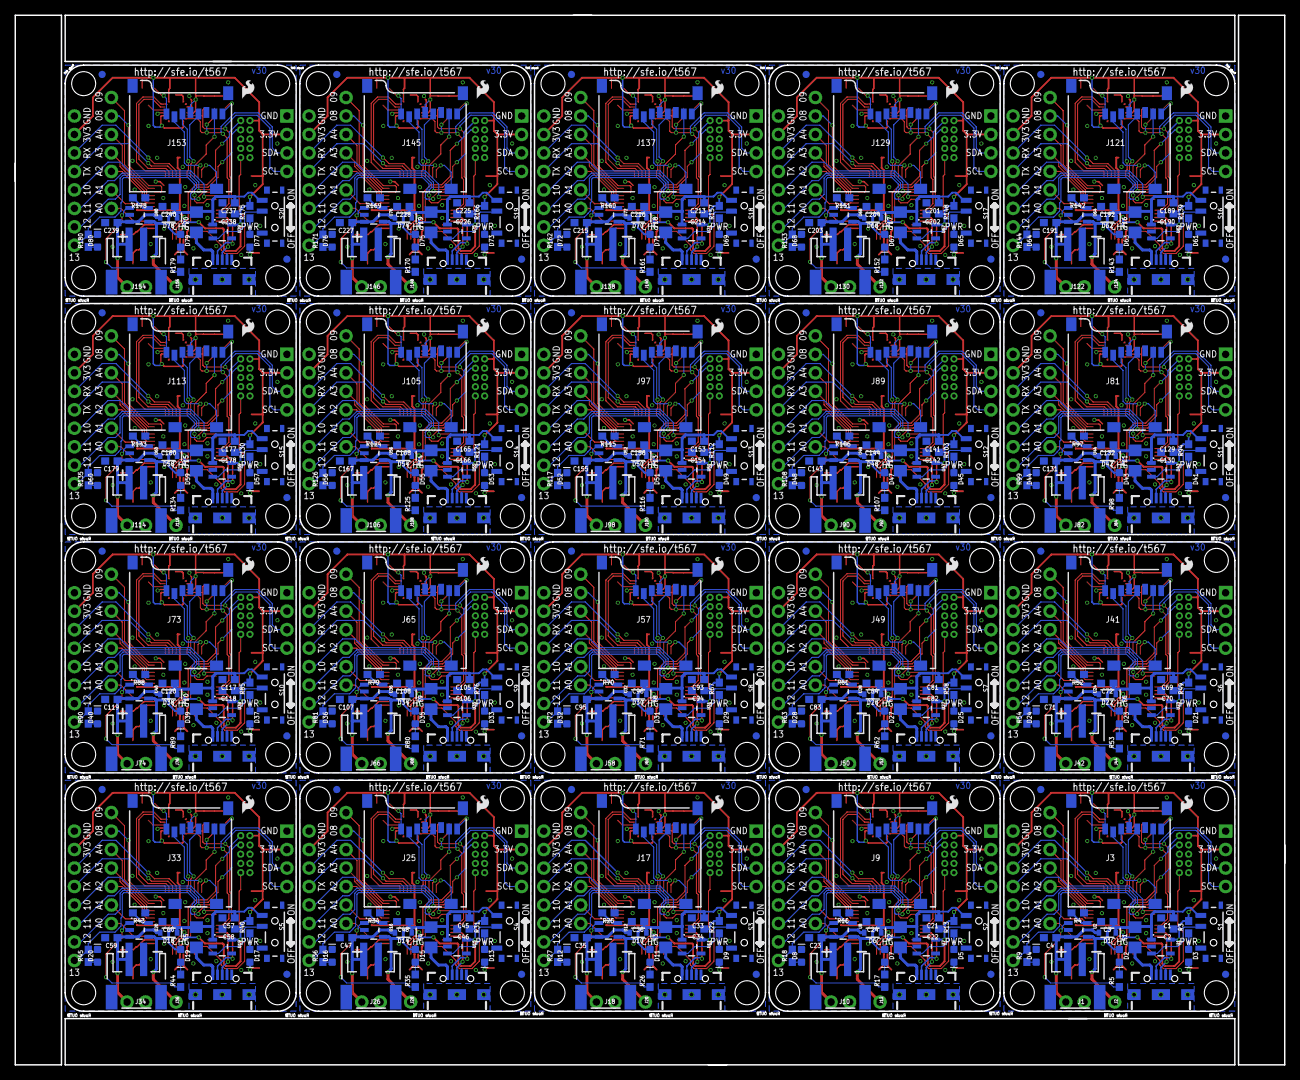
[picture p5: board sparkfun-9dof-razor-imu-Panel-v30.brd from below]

Board: 2 copper layers, 174.5 x 144.3 mm, 1103 parts (440 on the bottom side), 920 nets.

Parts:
C1, C21, C33, C45, C57, C69, C81, C93, C105, C117, C129, C141, C153, C165, C177, C189, C201, C213, C225, C237: 1.0uF; 0603
C2, C22, C34, C46, C58, C70, C82, C94, C106, C118, C130, C142, C154, C166, C178, C190, C202, C214, C226, C238: 2.2uF; 0603
C3, C4, C23, C24, C35, C36, C47, C48, C59, C60, C71, C72, C83, C84, C95, C96, C107, C108, C119, C120, C131, C132, C143, C144, C155, C156, C167, C168, C179, C180, C191, C192, C203, C204, C215, C216, C227, C228, C239, C240: 4.7uF; 0603
C5, C6, C7, C8, C9, C11, C13, C14, C15, C16, C17, C18, C25, C26, C27, C28, C29, C30, C37, C38, C39, C40, C41, C42, C49, C50, C51, C52, C53, C54, C61, C62, C63, C64, C65, C66, C73, C74, C75, C76, C77, C78, C85, C86, C87, C88, C89, C90, C97, C98, C99, C100, C101, C102, C109, C110, C111, C112, C113, C114, C121, C122, C123, C124, C125, C126, C133, C134, C135, C136, C137, C138, C145, C146, C147, C148, C149, C150, C157, C158, C159, C160, C161, C162, C169, C170, C171, C172, C173, C174, C181, C182, C183, C184, C185, C186, C193, C194, C195, C196, C197, C198, C205, C206, C207, C208, C209, C210, C217, C218, C219, C220, C221, C222, C229, C230, C231, C232, C233, C234: 0.1uF; 0603
C10, C12, C19, C20, C31, C32, C43, C44, C55, C56, C67, C68, C79, C80, C91, C92, C103, C104, C115, C116, C127, C128, C139, C140, C151, C152, C163, C164, C175, C176, C187, C188, C199, C200, C211, C212, C223, C224, C235, C236: 15pF; 0603
D1, D6, D10, D14, D18, D22, D26, D30, D34, D38, D42, D46, D50, D54, D58, D62, D66, D70, D74, D78: 1A/23V/620mV; SOD-323
D2, D7, D11, D15, D19, D23, D27, D31, D35, D39, D43, D47, D51, D55, D59, D63, D67, D71, D75, D79: Yellow; LED-0603
D3, D5, D9, D13, D17, D21, D25, D29, D33, D37, D41, D45, D49, D53, D57, D61, D65, D69, D73, D77: RED; LED-0603
D4, D8, D12, D16, D20, D24, D28, D32, D36, D40, D44, D48, D52, D56, D60, D64, D68, D72, D76, D80: BLUE; LED-0603
E$1: FIDUCIAL-1.5X3
E$7, E$8: FIDUCIAL-1X2
F1, F2, F3, F4, F5, F6, F7, F8, F9, F10, F11, F12, F13, F14, F15, F16, F17, F18, F19, F20: 6V/0.5A; 1206
FD1, FD2, FD3, FD4, FD5, FD6, FD7, FD8, FD9, FD10, FD11, FD12, FD13, FD14, FD15, FD16, FD17, FD18, FD19, FD20, FD21, FD22, FD23, FD24, FD25, FD26, FD27, FD28, FD29, FD30, FD31, FD32, FD33, FD34, FD35, FD36, FD37, FD38, FD39, FD40, FD41, FD42, FD43, FD44, FD45, FD46, FD47, FD48, FD49, FD50, FD51, FD52, FD53, FD54, FD55, FD56, FD57, FD58, FD59, FD60, FD61, FD62, FD63, FD64, FD65, FD66, FD67, FD68, FD69, FD70, FD71, FD72, FD73, FD74, FD75, FD76, FD77, FD78, FD79, FD80: FIDUCIAL1X2; FIDUCIAL-1X2
H1, H2, H3, H4, H5, H6, H7, H8, H9, H10, H11, H12, H13, H14, H15, H16, H17, H18, H19, H20, H21, H22, H23, H24, H25, H26, H27, H28, H29, H30, H31, H32, H33, H34, H35, H36, H37, H38, H39, H40, H41, H42, H43, H44, H45, H46, H47, H48, H49, H50, H51, H52, H53, H54, H55, H56, H57, H58, H59, H60, H61, H62, H63, H64, H65, H66, H67, H68, H69, H70, H71, H72, H73, H74, H75, H76, H77, H78, H79, H80: STAND-OFF
J1, J10, J18, J26, J34, J42, J50, J58, J66, J74, J82, J90, J98, J106, J114, J122, J130, J138, J146, J154: LiPo; JST-2-SMD
J2, J12, J20, J28, J36, J44, J52, J60, J68, J76, J84, J92, J100, J108, J116, J124, J132, J140, J148, J156: USB-B-MICRO-SMD_V03
J3, J9, J17, J25, J33, J41, J49, J57, J65, J73, J81, J89, J97, J105, J113, J121, J129, J137, J145, J153: USD_CONNECTOR; MICRO-SD-SOCKET-PP
J4, J14, J22, J30, J38, J46, J54, J62, J70, J78, J86, J94, J102, J110, J118, J126, J134, J142, J150, J158: 1X07
J5, J13, J21, J29, J37, J45, J53, J61, J69, J77, J85, J93, J101, J109, J117, J125, J133, J141, J149, J157: 1X08
J6, J15, J23, J31, J39, J47, J55, J63, J71, J79, J87, J95, J103, J111, J119, J127, J135, J143, J151, J159: 1X02
J7, J11, J19, J27, J35, J43, J51, J59, J67, J75, J83, J91, J99, J107, J115, J123, J131, J139, J147, J155: 1X04
J8, J16, J24, J32, J40, J48, J56, J64, J72, J80, J88, J96, J104, J112, J120, J128, J136, J144, J152, J160: 1X01
JP1, JP4, JP6, JP8, JP10, JP12, JP14, JP16, JP18, JP20, JP22, JP24, JP26, JP28, JP30, JP32, JP34, JP36, JP38, JP40: LED; SMT-JUMPER_2_NC_PASTE_NO-SILK
JP2, JP3, JP5, JP7, JP9, JP11, JP13, JP15, JP17, JP19, JP21, JP23, JP25, JP27, JP29, JP31, JP33, JP35, JP37, JP39: CORTEX_DEBUGPTH; 2X5-PTH-1.27MM
LOGO1, LOGO4, LOGO7, LOGO10, LOGO13, LOGO16, LOGO19, LOGO22, LOGO25, LOGO28, LOGO31, LOGO34, LOGO37, LOGO40, LOGO43, LOGO46, LOGO49, LOGO52, LOGO55, LOGO58: SFE_LOGO_FLAME.1_INCH; SFE_LOGO_FLAME_.1
LOGO2, LOGO5, LOGO8, LOGO11, LOGO14, LOGO17, LOGO20, LOGO23, LOGO26, LOGO29, LOGO32, LOGO35, LOGO38, LOGO41, LOGO44, LOGO47, LOGO50, LOGO53, LOGO56, LOGO59: OSHW-LOGOS; OSHW-LOGO-S
LOGO3, LOGO6, LOGO9, LOGO12, LOGO15, LOGO18, LOGO21, LOGO24, LOGO27, LOGO30, LOGO33, LOGO36, LOGO39, LOGO42, LOGO45, LOGO48, LOGO51, LOGO54, LOGO57, LOGO60: SFE_LOGO_NAME.1_INCH; SFE_LOGO_NAME_.1
R1, R2, R10, R11, R19, R20, R28, R29, R37, R38, R46, R47, R55, R56, R64, R65, R73, R74, R82, R83, R91, R92, R100, R101, R109, R110, R118, R119, R127, R128, R136, R137, R145, R146, R154, R155, R163, R164, R172, R173: 4.7k; 0603
R3, R5, R9, R13, R17, R18, R22, R26, R27, R31, R35, R36, R40, R44, R45, R49, R53, R54, R58, R62, R63, R67, R71, R72, R76, R80, R81, R85, R89, R90, R94, R98, R99, R103, R107, R108, R112, R116, R117, R121, R125, R126, R130, R134, R135, R139, R143, R144, R148, R152, R153, R157, R161, R162, R166, R170, R171, R175, R179, R180: 1k; 0603
R4, R16, R25, R34, R43, R52, R61, R70, R79, R88, R97, R106, R115, R124, R133, R142, R151, R160, R169, R178: 2.2k; 0603
R6, R7, R14, R15, R23, R24, R32, R33, R41, R42, R50, R51, R59, R60, R68, R69, R77, R78, R86, R87, R95, R96, R104, R105, R113, R114, R122, R123, R131, R132, R140, R141, R149, R150, R158, R159, R167, R168, R176, R177: 100k; 0603
R8, R12, R21, R30, R39, R48, R57, R66, R75, R84, R93, R102, R111, R120, R129, R138, R147, R156, R165, R174: 10k; 0603
S1, S2, S3, S4, S5, S6, S7, S8, S9, S10, S11, S12, S13, S14, S15, S16, S17, S18, S19, S20: SWITCH-SPST-SMD-A
TP1, TP2, TP3, TP4, TP5, TP6, TP7, TP8, TP9, TP10, TP11, TP12, TP13, TP14, TP15, TP16, TP17, TP18, TP19, TP20, TP21, TP22, TP23, TP24, TP25, TP26, TP27, TP28, TP29, TP30, TP31, TP32, TP33, TP34, TP35, TP36, TP37, TP38, TP39, TP40: TEST-POINT3; PAD.03X.03
U1, U7, U11, U15, U19, U23, U27, U31, U35, U39, U43, U47, U51, U55, U59, U63, U67, U71, U75, U79: 3.3V; SOT23-5
U2, U8, U12, U16, U20, U24, U28, U32, U36, U40, U44, U48, U52, U56, U60, U64, U68, U72, U76, U80: MCP73831; SOT23-5
U3, U5, U9, U13, U17, U21, U25, U29, U33, U37, U41, U45, U49, U53, U57, U61, U65, U69, U73, U77: MPU-9250; QFN24-3X3
U4, U6, U10, U14, U18, U22, U26, U30, U34, U38, U42, U46, U50, U54, U58, U62, U66, U70, U74, U78: ATSAMD21G-A; TQFP-48
Y1, Y2, Y3, Y4, Y5, Y6, Y7, Y8, Y9, Y10, Y11, Y12, Y13, Y14, Y15, Y16, Y17, Y18, Y19, Y20: 32.768kHz; CRYSTAL-SMD-3.2X1.5MM

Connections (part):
3.3V: C2.1, C5.1, C7.1, C8.1, C11.1, J3.VCC, J5.7, J7.2, JP3.1, R1.2, R2.2, R3.2, R6.2, R7.2, R8.2, U1.5, U3.1, U3.8, U3.13, U3.22, U4.6, U4.17, U4.36, U4.44
3.3V1: C14.1, C15.1, C17.1, C18.1, C22.1, J9.VCC, J11.2, J13.7, JP2.1, R10.2, R11.2, R12.2, R13.2, R14.2, R15.2, U5.1, U5.8, U5.13, U5.22, U6.6, U6.17, U6.36, U6.44, U7.5
3.3V2: C26.1, C27.1, C29.1, C30.1, C34.1, J17.VCC, J19.2, J21.7, JP5.1, R19.2, R20.2, R21.2, R22.2, R23.2, R24.2, U9.1, U9.8, U9.13, U9.22, U10.6, U10.17, U10.36, U10.44, U11.5
3.3V3: C38.1, C39.1, C41.1, C42.1, C46.1, J25.VCC, J27.2, J29.7, JP7.1, R28.2, R29.2, R30.2, R31.2, R32.2, R33.2, U13.1, U13.8, U13.13, U13.22, U14.6, U14.17, U14.36, U14.44, U15.5
3.3V4: C50.1, C51.1, C53.1, C54.1, C58.1, J33.VCC, J35.2, J37.7, JP9.1, R37.2, R38.2, R39.2, R40.2, R41.2, R42.2, U17.1, U17.8, U17.13, U17.22, U18.6, U18.17, U18.36, U18.44, U19.5
3.3V5: C62.1, C63.1, C65.1, C66.1, C70.1, J41.VCC, J43.2, J45.7, JP11.1, R46.2, R47.2, R48.2, R49.2, R50.2, R51.2, U21.1, U21.8, U21.13, U21.22, U22.6, U22.17, U22.36, U22.44, U23.5
3.3V6: C74.1, C75.1, C77.1, C78.1, C82.1, J49.VCC, J51.2, J53.7, JP13.1, R55.2, R56.2, R57.2, R58.2, R59.2, R60.2, U25.1, U25.8, U25.13, U25.22, U26.6, U26.17, U26.36, U26.44, U27.5
3.3V7: C86.1, C87.1, C89.1, C90.1, C94.1, J57.VCC, J59.2, J61.7, JP15.1, R64.2, R65.2, R66.2, R67.2, R68.2, R69.2, U29.1, U29.8, U29.13, U29.22, U30.6, U30.17, U30.36, U30.44, U31.5
3.3V8: C98.1, C99.1, C101.1, C102.1, C106.1, J65.VCC, J67.2, J69.7, JP17.1, R73.2, R74.2, R75.2, R76.2, R77.2, R78.2, U33.1, U33.8, U33.13, U33.22, U34.6, U34.17, U34.36, U34.44, U35.5
3.3V9: C110.1, C111.1, C113.1, C114.1, C118.1, J73.VCC, J75.2, J77.7, JP19.1, R82.2, R83.2, R84.2, R85.2, R86.2, R87.2, U37.1, U37.8, U37.13, U37.22, U38.6, U38.17, U38.36, U38.44, U39.5
3.3V10: C122.1, C123.1, C125.1, C126.1, C130.1, J81.VCC, J83.2, J85.7, JP21.1, R91.2, R92.2, R93.2, R94.2, R95.2, R96.2, U41.1, U41.8, U41.13, U41.22, U42.6, U42.17, U42.36, U42.44, U43.5
3.3V11: C134.1, C135.1, C137.1, C138.1, C142.1, J89.VCC, J91.2, J93.7, JP23.1, R100.2, R101.2, R102.2, R103.2, R104.2, R105.2, U45.1, U45.8, U45.13, U45.22, U46.6, U46.17, U46.36, U46.44, U47.5
3.3V12: C146.1, C147.1, C149.1, C150.1, C154.1, J97.VCC, J99.2, J101.7, JP25.1, R109.2, R110.2, R111.2, R112.2, R113.2, R114.2, U49.1, U49.8, U49.13, U49.22, U50.6, U50.17, U50.36, U50.44, U51.5
3.3V13: C158.1, C159.1, C161.1, C162.1, C166.1, J105.VCC, J107.2, J109.7, JP27.1, R118.2, R119.2, R120.2, R121.2, R122.2, R123.2, U53.1, U53.8, U53.13, U53.22, U54.6, U54.17, U54.36, U54.44, U55.5
3.3V14: C170.1, C171.1, C173.1, C174.1, C178.1, J113.VCC, J115.2, J117.7, JP29.1, R127.2, R128.2, R129.2, R130.2, R131.2, R132.2, U57.1, U57.8, U57.13, U57.22, U58.6, U58.17, U58.36, U58.44, U59.5
3.3V15: C182.1, C183.1, C185.1, C186.1, C190.1, J121.VCC, J123.2, J125.7, JP31.1, R136.2, R137.2, R138.2, R139.2, R140.2, R141.2, U61.1, U61.8, U61.13, U61.22, U62.6, U62.17, U62.36, U62.44, U63.5
3.3V16: C194.1, C195.1, C197.1, C198.1, C202.1, J129.VCC, J131.2, J133.7, JP33.1, R145.2, R146.2, R147.2, R148.2, R149.2, R150.2, U65.1, U65.8, U65.13, U65.22, U66.6, U66.17, U66.36, U66.44, U67.5
3.3V17: C206.1, C207.1, C209.1, C210.1, C214.1, J137.VCC, J139.2, J141.7, JP35.1, R154.2, R155.2, R156.2, R157.2, R158.2, R159.2, U69.1, U69.8, U69.13, U69.22, U70.6, U70.17, U70.36, U70.44, U71.5
3.3V18: C218.1, C219.1, C221.1, C222.1, C226.1, J145.VCC, J147.2, J149.7, JP37.1, R163.2, R164.2, R165.2, R166.2, R167.2, R168.2, U73.1, U73.8, U73.13, U73.22, U74.6, U74.17, U74.36, U74.44, U75.5
3.3V19: C230.1, C231.1, C233.1, C234.1, C238.1, J153.VCC, J155.2, J157.7, JP39.1, R172.2, R173.2, R174.2, R175.2, R176.2, R177.2, U77.1, U77.8, U77.13, U77.22, U78.6, U78.17, U78.36, U78.44, U79.5
!RESET: JP3.10, R8.1, U4.40
!RESET1: JP2.10, R12.1, U6.40
!RESET2: JP5.10, R21.1, U10.40
!RESET3: JP7.10, R30.1, U14.40
!RESET4: JP9.10, R39.1, U18.40
!RESET5: JP11.10, R48.1, U22.40
!RESET6: JP13.10, R57.1, U26.40
!RESET7: JP15.10, R66.1, U30.40
!RESET8: JP17.10, R75.1, U34.40
!RESET9: JP19.10, R84.1, U38.40
!RESET10: JP21.10, R93.1, U42.40
!RESET11: JP23.10, R102.1, U46.40
!RESET12: JP25.10, R111.1, U50.40
!RESET13: JP27.10, R120.1, U54.40
!RESET14: JP29.10, R129.1, U58.40
!RESET15: JP31.10, R138.1, U62.40
!RESET16: JP33.10, R147.1, U66.40
!RESET17: JP35.10, R156.1, U70.40
!RESET18: JP37.10, R165.1, U74.40
!RESET19: JP39.10, R174.1, U78.40
A0: J4.1, U4.3
A1: J4.2, U4.7
A2: J4.3, U4.8
A3: J4.4, U4.9
A4: J4.5, U4.10
A6: J14.2, U6.7
A7: J14.1, U6.3
A8: J14.3, U6.8
A9: J14.4, U6.9
A10: J14.5, U6.10
A12: J22.2, U10.7
A13: J22.1, U10.3
A14: J22.3, U10.8
A15: J22.4, U10.9
A16: J22.5, U10.10
A18: J30.2, U14.7
A19: J30.1, U14.3
A20: J30.3, U14.8
A21: J30.4, U14.9
A22: J30.5, U14.10
A24: J38.2, U18.7
A25: J38.1, U18.3
A26: J38.3, U18.8
A27: J38.4, U18.9
A28: J38.5, U18.10
A30: J46.2, U22.7
A31: J46.1, U22.3
A32: J46.3, U22.8
A33: J46.4, U22.9
A34: J46.5, U22.10
A36: J54.2, U26.7
A37: J54.1, U26.3
A38: J54.3, U26.8
A39: J54.4, U26.9
A40: J54.5, U26.10
A42: J62.2, U30.7
A43: J62.1, U30.3
A44: J62.3, U30.8
A45: J62.4, U30.9
A46: J62.5, U30.10
A48: J70.2, U34.7
A49: J70.1, U34.3
A50: J70.3, U34.8
A51: J70.4, U34.9
A52: J70.5, U34.10
A54: J78.2, U38.7
A55: J78.1, U38.3
A56: J78.3, U38.8
A57: J78.4, U38.9
A58: J78.5, U38.10
A60: J86.2, U42.7
A61: J86.1, U42.3
A62: J86.3, U42.8
A63: J86.4, U42.9
A64: J86.5, U42.10
A66: J94.2, U46.7
A67: J94.1, U46.3
A68: J94.3, U46.8
A69: J94.4, U46.9
A70: J94.5, U46.10
A72: J102.2, U50.7
A73: J102.1, U50.3
A74: J102.3, U50.8
A75: J102.4, U50.9
A76: J102.5, U50.10
A78: J110.2, U54.7
A79: J110.1, U54.3
A80: J110.3, U54.8
A81: J110.4, U54.9
A82: J110.5, U54.10
A84: J118.2, U58.7
A85: J118.1, U58.3
A86: J118.3, U58.8
A87: J118.4, U58.9
A88: J118.5, U58.10
A90: J126.2, U62.7
A91: J126.1, U62.3
A92: J126.3, U62.8
A93: J126.4, U62.9
A94: J126.5, U62.10
A96: J134.2, U66.7
A97: J134.1, U66.3
A98: J134.3, U66.8
A99: J134.4, U66.9
A100: J134.5, U66.10
A102: J142.2, U70.7
A103: J142.1, U70.3
A104: J142.3, U70.8
A105: J142.4, U70.9
A106: J142.5, U70.10
A108: J150.2, U74.7
A109: J150.1, U74.3
A110: J150.3, U74.8
A111: J150.4, U74.9
A112: J150.5, U74.10
A114: J158.2, U78.7
A115: J158.1, U78.3
A116: J158.3, U78.8
A117: J158.4, U78.9
A118: J158.5, U78.10
CHG_LED: R5.1, U2.1
CHG_LED1: R17.1, U8.1
CHG_LED2: R26.1, U12.1
CHG_LED3: R35.1, U16.1
CHG_LED4: R44.1, U20.1
CHG_LED5: R53.1, U24.1
CHG_LED6: R62.1, U28.1
CHG_LED7: R71.1, U32.1
CHG_LED8: R80.1, U36.1
CHG_LED9: R89.1, U40.1
CHG_LED10: R98.1, U44.1
CHG_LED11: R107.1, U48.1
CHG_LED12: R116.1, U52.1
CHG_LED13: R125.1, U56.1
CHG_LED14: R134.1, U60.1
CHG_LED15: R143.1, U64.1
CHG_LED16: R152.1, U68.1
CHG_LED17: R161.1, U72.1
CHG_LED18: R170.1, U76.1
CHG_LED19: R179.1, U80.1
D0/RXI: J5.6, U4.16
D0/RXI1: J13.6, U6.16
D0/RXI2: J21.6, U10.16
D0/RXI3: J29.6, U14.16
D0/RXI4: J37.6, U18.16
D0/RXI5: J45.6, U22.16
D0/RXI6: J53.6, U26.16
D0/RXI7: J61.6, U30.16
D0/RXI8: J69.6, U34.16
D0/RXI9: J77.6, U38.16
D0/RXI10: J85.6, U42.16
D0/RXI11: J93.6, U46.16
D0/RXI12: J101.6, U50.16
D0/RXI13: J109.6, U54.16
D0/RXI14: J117.6, U58.16
D0/RXI15: J125.6, U62.16
D0/RXI16: J133.6, U66.16
D0/RXI17: J141.6, U70.16
D0/RXI18: J149.6, U74.16
D0/RXI19: J157.6, U78.16
D1/TXO: J5.5, U4.15
D1/TXO1: J13.5, U6.15
D1/TXO2: J21.5, U10.15
D1/TXO3: J29.5, U14.15
D1/TXO4: J37.5, U18.15
D1/TXO5: J45.5, U22.15
D1/TXO6: J53.5, U26.15
D1/TXO7: J61.5, U30.15
D1/TXO8: J69.5, U34.15
D1/TXO9: J77.5, U38.15
D1/TXO10: J85.5, U42.15
D1/TXO11: J93.5, U46.15
D1/TXO12: J101.5, U50.15
D1/TXO13: J109.5, U54.15
D1/TXO14: J117.5, U58.15
D1/TXO15: J125.5, U62.15
D1/TXO16: J133.5, U66.15
D1/TXO17: J141.5, U70.15
D1/TXO18: J149.5, U74.15
D1/TXO19: J157.5, U78.15
D2/SD_CD: J3.CD1, U4.23
D2/SD_CD1: J9.CD1, U6.23
D2/SD_CD2: J17.CD1, U10.23
D2/SD_CD3: J25.CD1, U14.23
D2/SD_CD4: J33.CD1, U18.23
D2/SD_CD5: J41.CD1, U22.23
D2/SD_CD6: J49.CD1, U26.23
D2/SD_CD7: J57.CD1, U30.23
D2/SD_CD8: J65.CD1, U34.23
D2/SD_CD9: J73.CD1, U38.23
D2/SD_CD10: J81.CD1, U42.23
D2/SD_CD11: J89.CD1, U46.23
D2/SD_CD12: J97.CD1, U50.23
D2/SD_CD13: J105.CD1, U54.23
D2/SD_CD14: J113.CD1, U58.23
D2/SD_CD15: J121.CD1, U62.23
D2/SD_CD16: J129.CD1, U66.23
D2/SD_CD17: J137.CD1, U70.23
D2/SD_CD18: J145.CD1, U74.23
D2/SD_CD19: J153.CD1, U78.23
D3/FSYNC: U3.11, U4.14
D3/FSYNC1: U5.11, U6.14
D3/FSYNC2: U9.11, U10.14
D3/FSYNC3: U13.11, U14.14
D3/FSYNC4: U17.11, U18.14
D3/FSYNC5: U21.11, U22.14
D3/FSYNC6: U25.11, U26.14
D3/FSYNC7: U29.11, U30.14
D3/FSYNC8: U33.11, U34.14
D3/FSYNC9: U37.11, U38.14
D3/FSYNC10: U41.11, U42.14
D3/FSYNC11: U45.11, U46.14
D3/FSYNC12: U49.11, U50.14
D3/FSYNC13: U53.11, U54.14
D3/FSYNC14: U57.11, U58.14
D3/FSYNC15: U61.11, U62.14
D3/FSYNC16: U65.11, U66.14
D3/FSYNC17: U69.11, U70.14
D3/FSYNC18: U73.11, U74.14
D3/FSYNC19: U77.11, U78.14
D4: J13.2, U6.28
D4/INT: U3.12, U4.13
D4/INT1: U5.12, U6.13
D4/INT2: U9.12, U10.13
D4/INT3: U13.12, U14.13
D4/INT4: U17.12, U18.13
D4/INT5: U21.12, U22.13
D4/INT6: U25.12, U26.13
D4/INT7: U29.12, U30.13
D4/INT8: U33.12, U34.13
D4/INT9: U37.12, U38.13
D4/INT10: U41.12, U42.13
D4/INT11: U45.12, U46.13
D4/INT12: U49.12, U50.13
D4/INT13: U53.12, U54.13
D4/INT14: U57.12, U58.13
D4/INT15: U61.12, U62.13
D4/INT16: U65.12, U66.13
D4/INT17: U69.12, U70.13
D4/INT18: U73.12, U74.13
D4/INT19: U77.12, U78.13
D8: J4.6, U4.11
D9: J4.7, U4.12
D10: J5.4, U4.27
D11: J5.3, U4.25
D12: J5.2, U4.28
D13: J5.1, R9.2, U4.26
D14: J13.4, U6.27
D15: J13.3, U6.25
D16: J13.1, R18.2, U6.26
D17: J14.6, U6.11
D18: J14.7, U6.12
D22: J21.2, U10.28
D23: J21.4, U10.27
D24: J21.3, U10.25
D25: J21.1, R27.2, U10.26
D26: J22.6, U10.11
D27: J22.7, U10.12
D31: J29.2, U14.28
D32: J29.4, U14.27
D33: J29.3, U14.25
D34: J29.1, R36.2, U14.26
D35: J30.6, U14.11
D36: J30.7, U14.12
D40: J37.2, U18.28
D41: J37.4, U18.27
D42: J37.3, U18.25
D43: J37.1, R45.2, U18.26
D44: J38.6, U18.11
D45: J38.7, U18.12
D49: J45.2, U22.28
D50: J45.4, U22.27
D51: J45.3, U22.25
D52: J45.1, R54.2, U22.26
D53: J46.6, U22.11
D54: J46.7, U22.12
D58: J53.2, U26.28
D59: J53.4, U26.27
D60: J53.3, U26.25
D61: J53.1, R63.2, U26.26
D62: J54.6, U26.11
D63: J54.7, U26.12
D67: J61.2, U30.28
D68: J61.4, U30.27
D69: J61.3, U30.25
D70: J61.1, R72.2, U30.26
D71: J62.6, U30.11
D72: J62.7, U30.12
D76: J69.2, U34.28
D77: J69.4, U34.27
D78: J69.3, U34.25
D79: J69.1, R81.2, U34.26
D80: J70.6, U34.11
D81: J70.7, U34.12
D85: J77.2, U38.28
D86: J77.4, U38.27
D87: J77.3, U38.25
D88: J77.1, R90.2, U38.26
D89: J78.6, U38.11
D90: J78.7, U38.12
D94: J85.2, U42.28
D95: J85.4, U42.27
D96: J85.3, U42.25
D97: J85.1, R99.2, U42.26
D98: J86.6, U42.11
D99: J86.7, U42.12
D103: J93.2, U46.28
D104: J93.4, U46.27
D105: J93.3, U46.25
D106: J93.1, R108.2, U46.26
D107: J94.6, U46.11
D108: J94.7, U46.12
D112: J101.2, U50.28
D113: J101.4, U50.27
D114: J101.3, U50.25
D115: J101.1, R117.2, U50.26
D116: J102.6, U50.11
D117: J102.7, U50.12
D121: J109.2, U54.28
D122: J109.4, U54.27
D123: J109.3, U54.25
D124: J109.1, R126.2, U54.26
D125: J110.6, U54.11
D126: J110.7, U54.12
D130: J117.2, U58.28
D131: J117.4, U58.27
D132: J117.3, U58.25
D133: J117.1, R135.2, U58.26
D134: J118.6, U58.11
D135: J118.7, U58.12
D139: J125.2, U62.28
D140: J125.4, U62.27
D141: J125.3, U62.25
D142: J125.1, R144.2, U62.26
D143: J126.6, U62.11
D144: J126.7, U62.12
D148: J133.2, U66.28
D149: J133.4, U66.27
D150: J133.3, U66.25
D151: J133.1, R153.2, U66.26
D152: J134.6, U66.11
D153: J134.7, U66.12
D157: J141.2, U70.28
D158: J141.4, U70.27
D159: J141.3, U70.25
D160: J141.1, R162.2, U70.26
D161: J142.6, U70.11
D162: J142.7, U70.12
D166: J149.2, U74.28
D167: J149.4, U74.27
D168: J149.3, U74.25
D169: J149.1, R171.2, U74.26
D170: J150.6, U74.11
D171: J150.7, U74.12
D175: J157.2, U78.28
D176: J157.4, U78.27
D177: J157.3, U78.25
D178: J157.1, R180.2, U78.26
D179: J158.6, U78.11
D180: J158.7, U78.12
D+: J2.D+, U4.34
D+1: J12.D+, U6.34
D+2: J20.D+, U10.34
D+3: J28.D+, U14.34
D+4: J36.D+, U18.34
D+5: J44.D+, U22.34
D+6: J52.D+, U26.34
D+7: J60.D+, U30.34
D+8: J68.D+, U34.34
D+9: J76.D+, U38.34
D+10: J84.D+, U42.34
D+11: J92.D+, U46.34
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

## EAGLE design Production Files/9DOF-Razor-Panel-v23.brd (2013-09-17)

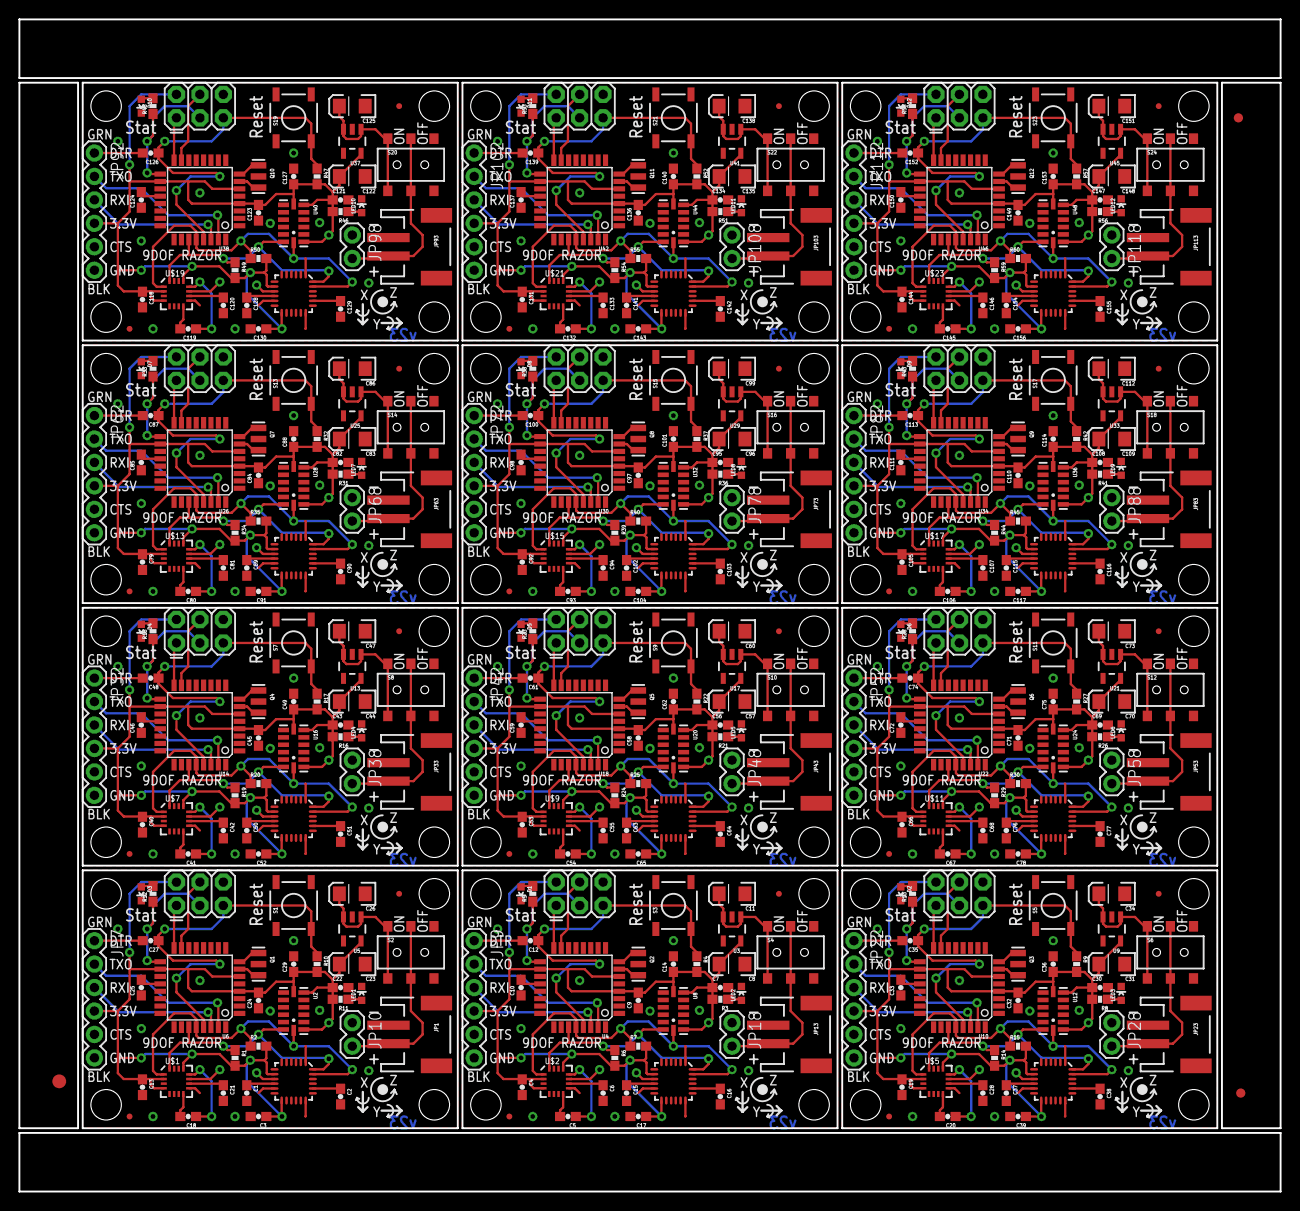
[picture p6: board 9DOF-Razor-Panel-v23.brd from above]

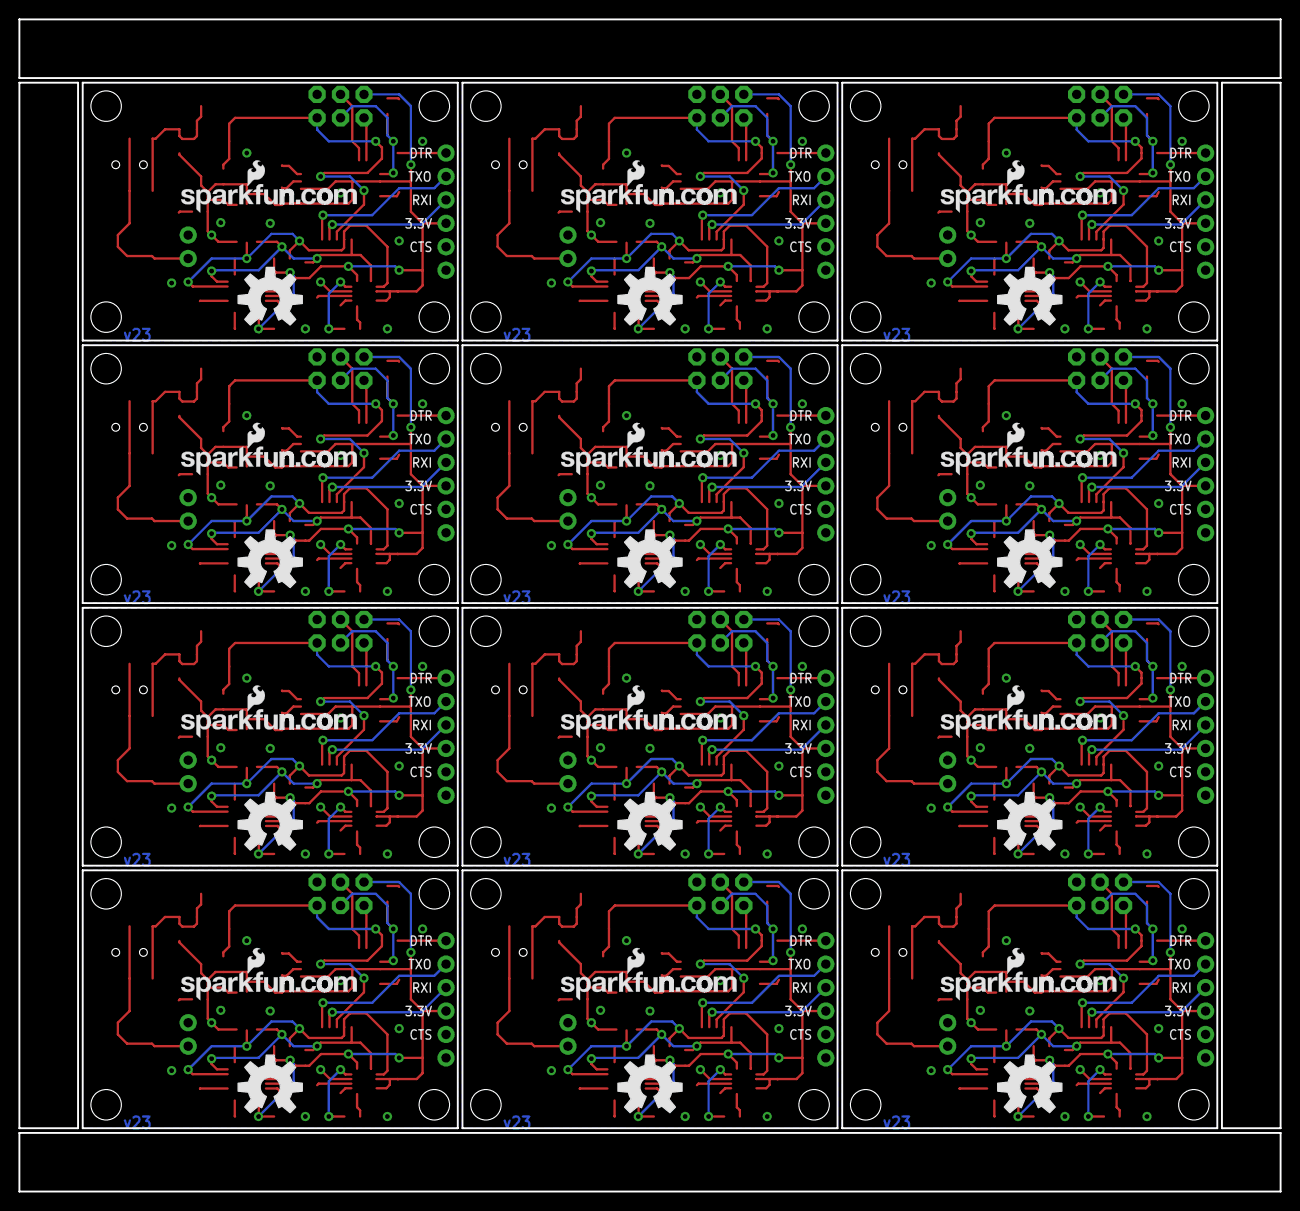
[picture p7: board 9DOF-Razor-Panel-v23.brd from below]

Board: 2 copper layers, 136.7 x 127.0 mm, 483 parts (24 on the bottom side), 276 nets.

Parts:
C1, C4, C7, C9, C10, C12, C13, C14, C15, C19, C22, C24, C25, C27, C29, C30, C32, C33, C35, C36, C37, C40, C43, C45, C46, C48, C49, C50, C53, C56, C58, C59, C61, C62, C63, C66, C69, C71, C72, C74, C75, C76, C79, C82, C84, C85, C87, C88, C89, C92, C95, C97, C98, C100, C101, C102, C105, C108, C110, C111, C113, C114, C115, C118, C121, C123, C124, C126, C127, C128, C131, C134, C136, C137, C139, C140, C141, C144, C147, C149, C150, C152, C153, C154: 0.1uF; 0603-CAP
C2, C16, C38, C51, C64, C77, C90, C103, C116, C129, C142, C155: 2.2nF; 0603-CAP
C3, C17, C39, C52, C65, C78, C91, C104, C117, C130, C143, C156: 10nF; 0603-CAP
C5, C18, C20, C41, C54, C67, C80, C93, C106, C119, C132, C145: 0.22uF; 0603-CAP
C6, C21, C28, C42, C55, C68, C81, C94, C107, C120, C133, C146: 4.7uF; 0603-CAP
C8, C11, C23, C26, C31, C34, C44, C47, C57, C60, C70, C73, C83, C86, C96, C99, C109, C112, C122, C125, C135, C138, C148, C151: 10uF; EIA3216
D1, D2, D3, D4, D5, D6, D7, D8, D9, D10, D11, D12: Green; LED-0603
E$1: FIDUCIAL-1.5X3
E$4, E$5: FIDUCIAL-1X2
J1, J2, J3, J4, J5, J6, J7, J8, J9, J10, J11, J12: AVR_SPI_PRG_6PTH; 2X3
JP1, JP13, JP23, JP33, JP43, JP53, JP63, JP73, JP83, JP93, JP103, JP113: JST_Horizontal; JST-2-SMD
JP2, JP4, JP5, JP6, JP14, JP15, JP16, JP17, JP24, JP25, JP26, JP27, JP34, JP35, JP36, JP37, JP44, JP45, JP46, JP47, JP54, JP55, JP56, JP57, JP64, JP65, JP66, JP67, JP74, JP75, JP76, JP77, JP84, JP85, JP86, JP87, JP94, JP95, JP96, JP97, JP104, JP105, JP106, JP107, JP114, JP115, JP116, JP117: STAND-OFF
JP3, JP8, JP21, JP31, JP41, JP51, JP61, JP71, JP81, JP91, JP101, JP111: LOGO-SFENEW; SFE-NEW-WEBLOGO
JP7, JP9, JP22, JP32, JP42, JP52, JP62, JP72, JP82, JP92, JP102, JP112: FTDI Basic; 1X06
JP10, JP18, JP28, JP38, JP48, JP58, JP68, JP78, JP88, JP98, JP108, JP118: JST_Horizontal; 1X02
JP11, JP12, JP19, JP20, JP29, JP30, JP39, JP40, JP49, JP50, JP59, JP60, JP69, JP70, JP79, JP80, JP89, JP90, JP99, JP100, JP109, JP110, JP119, JP120: FIDUCIAL1X2.5; FIDUCIAL-1X2.5
LED1, LED2, LED3, LED4, LED5, LED6, LED7, LED8, LED9, LED10, LED11, LED12: Red; LED-0603
Q1, Q2, Q3, Q4, Q5, Q6, Q7, Q8, Q9, Q10, Q11, Q12: 8MHz; RESONATOR-SMD
R1, R6, R14, R19, R24, R29, R34, R39, R44, R49, R54, R59: 4.7k; 0603-RES
R2, R7, R15, R20, R25, R30, R35, R40, R45, R50, R55, R60: 4.7K; 0603-RES
R3, R4, R8, R9, R10, R11, R16, R17, R21, R22, R26, R27, R31, R32, R36, R37, R41, R42, R46, R47, R51, R52, R56, R57: 10K; 0603-RES
R5, R12, R13, R18, R23, R28, R33, R38, R43, R48, R53, R58: 330; 0603-RES
S1, S3, S5, S7, S9, S11, S13, S15, S17, S19, S21, S23: Reset; TACTILE_SWITCH_SMD
S2, S4, S6, S8, S10, S12, S14, S16, S18, S20, S22, S24: Power; AYZ0202
U1, U7, U11, U15, U19, U23, U27, U31, U35, U39, U43, U47: ITG-32001:1; QFN-24_ITG3200_1:1
U2, U8, U12, U16, U20, U24, U28, U32, U36, U40, U44, U48: ADXL3451:1; LGA14
U3, U5, U9, U13, U17, U21, U25, U29, U33, U37, U41, U45: 3.3V; SOT23-5
U4, U6, U10, U14, U18, U22, U26, U30, U34, U38, U42, U46: ATMEGA328; TQFP32-08
U$1, U$2, U$5, U$7, U$9, U$11, U$13, U$15, U$17, U$19, U$21, U$23: HMC5883LSMD; 16LPCC
U$3, U$4, U$6, U$8, U$10, U$12, U$14, U$16, U$18, U$20, U$22, U$24: OSHW-LOGOL; OSHW-LOGO-L

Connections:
3.3V: C3.1, C13.1, C22.1, C23.A, C24.2, C29.1, J1.2, JP7.4, R1.2, R2.2, R10.2, R11.2, U1.8, U1.13, U2.1, U2.6, U2.7, U5.5, U6.4, U6.6, U6.18, U$1.2, U$1.4, U$1.13
3.3V1: C4.1, C7.1, C8.A, C9.2, C14.1, C17.1, J2.2, JP9.4, R3.2, R4.2, R6.2, R7.2, U3.5, U4.4, U4.6, U4.18, U7.8, U7.13, U8.1, U8.6, U8.7, U$2.2, U$2.4, U$2.13
3.3V2: C19.1, C30.1, C31.A, C32.2, C36.1, C39.1, J3.2, JP22.4, R8.2, R9.2, R14.2, R15.2, U9.5, U10.4, U10.6, U10.18, U11.8, U11.13, U12.1, U12.6, U12.7, U$5.2, U$5.4, U$5.13
3.3V3: C40.1, C43.1, C44.A, C45.2, C49.1, C52.1, J4.2, JP32.4, R16.2, R17.2, R19.2, R20.2, U13.5, U14.4, U14.6, U14.18, U15.8, U15.13, U16.1, U16.6, U16.7, U$7.2, U$7.4, U$7.13
3.3V4: C53.1, C56.1, C57.A, C58.2, C62.1, C65.1, J5.2, JP42.4, R21.2, R22.2, R24.2, R25.2, U17.5, U18.4, U18.6, U18.18, U19.8, U19.13, U20.1, U20.6, U20.7, U$9.2, U$9.4, U$9.13
3.3V5: C66.1, C69.1, C70.A, C71.2, C75.1, C78.1, J6.2, JP52.4, R26.2, R27.2, R29.2, R30.2, U21.5, U22.4, U22.6, U22.18, U23.8, U23.13, U24.1, U24.6, U24.7, U$11.2, U$11.4, U$11.13
3.3V6: C79.1, C82.1, C83.A, C84.2, C88.1, C91.1, J7.2, JP62.4, R31.2, R32.2, R34.2, R35.2, U25.5, U26.4, U26.6, U26.18, U27.8, U27.13, U28.1, U28.6, U28.7, U$13.2, U$13.4, U$13.13
3.3V7: C92.1, C95.1, C96.A, C97.2, C101.1, C104.1, J8.2, JP72.4, R36.2, R37.2, R39.2, R40.2, U29.5, U30.4, U30.6, U30.18, U31.8, U31.13, U32.1, U32.6, U32.7, U$15.2, U$15.4, U$15.13
3.3V8: C105.1, C108.1, C109.A, C110.2, C114.1, C117.1, J9.2, JP82.4, R41.2, R42.2, R44.2, R45.2, U33.5, U34.4, U34.6, U34.18, U35.8, U35.13, U36.1, U36.6, U36.7, U$17.2, U$17.4, U$17.13
3.3V9: C118.1, C121.1, C122.A, C123.2, C127.1, C130.1, J10.2, JP92.4, R46.2, R47.2, R49.2, R50.2, U37.5, U38.4, U38.6, U38.18, U39.8, U39.13, U40.1, U40.6, U40.7, U$19.2, U$19.4, U$19.13
3.3V10: C131.1, C134.1, C135.A, C136.2, C140.1, C143.1, J11.2, JP102.4, R51.2, R52.2, R54.2, R55.2, U41.5, U42.4, U42.6, U42.18, U43.8, U43.13, U44.1, U44.6, U44.7, U$21.2, U$21.4, U$21.13
3.3V11: C144.1, C147.1, C148.A, C149.2, C153.1, C156.1, J12.2, JP112.4, R56.2, R57.2, R59.2, R60.2, U45.5, U46.4, U46.6, U46.18, U47.8, U47.13, U48.1, U48.6, U48.7, U$23.2, U$23.4, U$23.13
AREF: C25.2, U6.20
AREF1: C10.2, U4.20
AREF2: C33.2, U10.20
AREF3: C46.2, U14.20
AREF4: C59.2, U18.20
AREF5: C72.2, U22.20
AREF6: C85.2, U26.20
AREF7: C98.2, U30.20
AREF8: C111.2, U34.20
AREF9: C124.2, U38.20
AREF10: C137.2, U42.20
AREF11: C150.2, U46.20
DTR: C27.2, JP7.1
DTR1: C12.2, JP9.1
DTR2: C35.2, JP22.1
DTR3: C48.2, JP32.1
DTR4: C61.2, JP42.1
DTR5: C74.2, JP52.1
DTR6: C87.2, JP62.1
DTR7: C100.2, JP72.1
DTR8: C113.2, JP82.1
DTR9: C126.2, JP92.1
DTR10: C139.2, JP102.1
DTR11: C152.2, JP112.1
GND: C1.2, C2.2, C3.2, C13.2, C21.2, C22.2, C23.C, C24.1, C25.1, C26.C, C29.2, D3.C, J1.6, JP1.1, JP7.5, JP7.6, JP10.1, LED1.C, Q1.2, S1.1, U1.1, U1.9, U1.11, U1.18, U2.2, U2.4, U2.5, U2.12, U5.2, U6.3, U6.5, U6.21, U$1.9, U$1.11
GND1: C4.2, C6.2, C7.2, C8.C, C9.1, C10.1, C11.C, C14.2, C15.2, C16.2, C17.2, D1.C, J2.6, JP9.5, JP9.6, JP13.1, JP18.1, LED2.C, Q2.2, S3.1, U3.2, U4.3, U4.5, U4.21, U7.1, U7.9, U7.11, U7.18, U8.2, U8.4, U8.5, U8.12, U$2.9, U$2.11
GND2: C19.2, C28.2, C30.2, C31.C, C32.1, C33.1, C34.C, C36.2, C37.2, C38.2, C39.2, D2.C, J3.6, JP22.5, JP22.6, JP23.1, JP28.1, LED3.C, Q3.2, S5.1, U9.2, U10.3, U10.5, U10.21, U11.1, U11.9, U11.11, U11.18, U12.2, U12.4, U12.5, U12.12, U$5.9, U$5.11
GND3: C40.2, C42.2, C43.2, C44.C, C45.1, C46.1, C47.C, C49.2, C50.2, C51.2, C52.2, D4.C, J4.6, JP32.5, JP32.6, JP33.1, JP38.1, LED4.C, Q4.2, S7.1, U13.2, U14.3, U14.5, U14.21, U15.1, U15.9, U15.11, U15.18, U16.2, U16.4, U16.5, U16.12, U$7.9, U$7.11
GND4: C53.2, C55.2, C56.2, C57.C, C58.1, C59.1, C60.C, C62.2, C63.2, C64.2, C65.2, D5.C, J5.6, JP42.5, JP42.6, JP43.1, JP48.1, LED5.C, Q5.2, S9.1, U17.2, U18.3, U18.5, U18.21, U19.1, U19.9, U19.11, U19.18, U20.2, U20.4, U20.5, U20.12, U$9.9, U$9.11
GND5: C66.2, C68.2, C69.2, C70.C, C71.1, C72.1, C73.C, C75.2, C76.2, C77.2, C78.2, D6.C, J6.6, JP52.5, JP52.6, JP53.1, JP58.1, LED6.C, Q6.2, S11.1, U21.2, U22.3, U22.5, U22.21, U23.1, U23.9, U23.11, U23.18, U24.2, U24.4, U24.5, U24.12, U$11.9, U$11.11
GND6: C79.2, C81.2, C82.2, C83.C, C84.1, C85.1, C86.C, C88.2, C89.2, C90.2, C91.2, D7.C, J7.6, JP62.5, JP62.6, JP63.1, JP68.1, LED7.C, Q7.2, S13.1, U25.2, U26.3, U26.5, U26.21, U27.1, U27.9, U27.11, U27.18, U28.2, U28.4, U28.5, U28.12, U$13.9, U$13.11
GND7: C92.2, C94.2, C95.2, C96.C, C97.1, C98.1, C99.C, C101.2, C102.2, C103.2, C104.2, D8.C, J8.6, JP72.5, JP72.6, JP73.1, JP78.1, LED8.C, Q8.2, S15.1, U29.2, U30.3, U30.5, U30.21, U31.1, U31.9, U31.11, U31.18, U32.2, U32.4, U32.5, U32.12, U$15.9, U$15.11
GND8: C105.2, C107.2, C108.2, C109.C, C110.1, C111.1, C112.C, C114.2, C115.2, C116.2, C117.2, D9.C, J9.6, JP82.5, JP82.6, JP83.1, JP88.1, LED9.C, Q9.2, S17.1, U33.2, U34.3, U34.5, U34.21, U35.1, U35.9, U35.11, U35.18, U36.2, U36.4, U36.5, U36.12, U$17.9, U$17.11
GND9: C118.2, C120.2, C121.2, C122.C, C123.1, C124.1, C125.C, C127.2, C128.2, C129.2, C130.2, D10.C, J10.6, JP92.5, JP92.6, JP93.1, JP98.1, LED10.C, Q10.2, S19.1, U37.2, U38.3, U38.5, U38.21, U39.1, U39.9, U39.11, U39.18, U40.2, U40.4, U40.5, U40.12, U$19.9, U$19.11
GND10: C131.2, C133.2, C134.2, C135.C, C136.1, C137.1, C138.C, C140.2, C141.2, C142.2, C143.2, D11.C, J11.6, JP102.5, JP102.6, JP103.1, JP108.1, LED11.C, Q11.2, S21.1, U41.2, U42.3, U42.5, U42.21, U43.1, U43.9, U43.11, U43.18, U44.2, U44.4, U44.5, U44.12, U$21.9, U$21.11
GND11: C144.2, C146.2, C147.2, C148.C, C149.1, C150.1, C151.C, C153.2, C154.2, C155.2, C156.2, D12.C, J12.6, JP112.5, JP112.6, JP113.1, JP118.1, LED12.C, Q12.2, S23.1, U45.2, U46.3, U46.5, U46.21, U47.1, U47.9, U47.11, U47.18, U48.2, U48.4, U48.5, U48.12, U$23.9, U$23.11
MISO: J1.1, U6.16
MISO1: J2.1, U4.16
MISO2: J3.1, U10.16
MISO3: J4.1, U14.16
MISO4: J5.1, U18.16
MISO5: J6.1, U22.16
MISO6: J7.1, U26.16
MISO7: J8.1, U30.16
MISO8: J9.1, U34.16
MISO9: J10.1, U38.16
MISO10: J11.1, U42.16
MISO11: J12.1, U46.16
MOSI: J1.4, U6.15
MOSI1: J2.4, U4.15
MOSI2: J3.4, U10.15
MOSI3: J4.4, U14.15
MOSI4: J5.4, U18.15
MOSI5: J6.4, U22.15
MOSI6: J7.4, U26.15
MOSI7: J8.4, U30.15
MOSI8: J9.4, U34.15
MOSI9: J10.4, U38.15
MOSI10: J11.4, U42.15
MOSI11: J12.4, U46.15
unnamed: C18.2, U$1.8
unnamed: C18.1, U$1.12
unnamed: C1.1, U1.10
unnamed: C2.1, U1.20
unnamed: LED2.A, R3.1
unnamed: C21.1, U$1.10
unnamed: D1.A, R5.2
unnamed: Q2.1, U4.8
unnamed: Q2.3, U4.7
unnamed: JP13.2, JP18.2, S4.2, S4.5
unnamed: C15.1, U7.10
unnamed: D3.A, R12.2
unnamed: Q1.1, U6.8
unnamed: Q1.3, U6.7
unnamed: JP1.2, JP10.2, S2.2, S2.5
unnamed: C16.1, U7.20
unnamed: C5.2, U$2.8
unnamed: C5.1, U$2.12
unnamed: C6.1, U$2.10
unnamed: LED3.A, R8.1
unnamed: D2.A, R13.2
unnamed: Q3.1, U10.8
unnamed: Q3.3, U10.7
unnamed: JP23.2, JP28.2, S6.2, S6.5
unnamed: C37.1, U11.10
unnamed: C38.1, U11.20
unnamed: C20.2, U$5.8
unnamed: C20.1, U$5.12
unnamed: C28.1, U$5.10
unnamed: LED4.A, R16.1
unnamed: D4.A, R18.2
unnamed: Q4.1, U14.8
unnamed: Q4.3, U14.7
unnamed: JP33.2, JP38.2, S8.2, S8.5
unnamed: C50.1, U15.10
unnamed: C51.1, U15.20
unnamed: C41.2, U$7.8
unnamed: LED1.A, R11.1
unnamed: C41.1, U$7.12
unnamed: C42.1, U$7.10
unnamed: LED5.A, R21.1
unnamed: D5.A, R23.2
unnamed: Q5.1, U18.8
unnamed: Q5.3, U18.7
unnamed: JP43.2, JP48.2, S10.2, S10.5
unnamed: C63.1, U19.10
unnamed: C64.1, U19.20
unnamed: C54.2, U$9.8
unnamed: C54.1, U$9.12
unnamed: C55.1, U$9.10
unnamed: LED6.A, R26.1
unnamed: D6.A, R28.2
unnamed: Q6.1, U22.8
unnamed: Q6.3, U22.7
unnamed: JP53.2, JP58.2, S12.2, S12.5
unnamed: C76.1, U23.10
unnamed: C77.1, U23.20
unnamed: C67.2, U$11.8
unnamed: C67.1, U$11.12
unnamed: C68.1, U$11.10
unnamed: LED7.A, R31.1
unnamed: D7.A, R33.2
unnamed: Q7.1, U26.8
unnamed: Q7.3, U26.7
unnamed: JP63.2, JP68.2, S14.2, S14.5
unnamed: C89.1, U27.10
unnamed: C90.1, U27.20
unnamed: C80.2, U$13.8
unnamed: C80.1, U$13.12
unnamed: C81.1, U$13.10
unnamed: LED8.A, R36.1
unnamed: D8.A, R38.2
unnamed: Q8.1, U30.8
unnamed: Q8.3, U30.7
unnamed: JP73.2, JP78.2, S16.2, S16.5
unnamed: C102.1, U31.10
unnamed: C103.1, U31.20
unnamed: C93.2, U$15.8
unnamed: C93.1, U$15.12
unnamed: C94.1, U$15.10
unnamed: LED9.A, R41.1
unnamed: D9.A, R43.2
unnamed: Q9.1, U34.8
unnamed: Q9.3, U34.7
unnamed: JP83.2, JP88.2, S18.2, S18.5
unnamed: C115.1, U35.10
unnamed: C116.1, U35.20
unnamed: C106.2, U$17.8
unnamed: C106.1, U$17.12
unnamed: C107.1, U$17.10
unnamed: LED10.A, R46.1
unnamed: D10.A, R48.2
unnamed: Q10.1, U38.8
unnamed: Q10.3, U38.7
unnamed: JP93.2, JP98.2, S20.2, S20.5
unnamed: C128.1, U39.10
unnamed: C129.1, U39.20
unnamed: C119.2, U$19.8
unnamed: C119.1, U$19.12
unnamed: C120.1, U$19.10
unnamed: LED11.A, R51.1
unnamed: D11.A, R53.2
unnamed: Q11.1, U42.8
unnamed: Q11.3, U42.7
unnamed: JP103.2, JP108.2, S22.2, S22.5
unnamed: C141.1, U43.10
unnamed: C142.1, U43.20
unnamed: C132.2, U$21.8
unnamed: C132.1, U$21.12
unnamed: C133.1, U$21.10
unnamed: LED12.A, R56.1
unnamed: D12.A, R58.2
unnamed: Q12.1, U46.8
unnamed: Q12.3, U46.7
unnamed: JP113.2, JP118.2, S24.2, S24.5
unnamed: C154.1, U47.10
unnamed: C155.1, U47.20
unnamed: C145.2, U$23.8
unnamed: C145.1, U$23.12
unnamed: C146.1, U$23.10
RAW: C26.A, S2.1, S2.4, U5.1, U5.3
RAW1: C11.A, S4.1, S4.4, U3.1, U3.3
RAW2: C34.A, S6.1, S6.4, U9.1, U9.3
RAW3: C47.A, S8.1, S8.4, U13.1, U13.3
RAW4: C60.A, S10.1, S10.4, U17.1, U17.3
RAW5: C73.A, S12.1, S12.4, U21.1, U21.3
RAW6: C86.A, S14.1, S14.4, U25.1, U25.3
RAW7: C99.A, S16.1, S16.4, U29.1, U29.3
RAW8: C112.A, S18.1, S18.4, U33.1, U33.3
RAW9: C125.A, S20.1, S20.4, U37.1, U37.3
RAW10: C138.A, S22.1, S22.4, U41.1, U41.3
RAW11: C151.A, S24.1, S24.4, U45.1, U45.3
RESET: C27.1, J1.5, R10.1, S1.3, U6.29
RESET1: C12.1, J2.5, R4.1, S3.3, U4.29
RESET2: C35.1, J3.5, R9.1, S5.3, U10.29
RESET3: C48.1, J4.5, R17.1, S7.3, U14.29
RESET4: C61.1, J5.5, R22.1, S9.3, U18.29
RESET5: C74.1, J6.5, R27.1, S11.3, U22.29
RESET6: C87.1, J7.5, R32.1, S13.3, U26.29
RESET7: C100.1, J8.5, R37.1, S15.3, U30.29
RESET8: C113.1, J9.5, R42.1, S17.3, U34.29
RESET9: C126.1, J10.5, R47.1, S19.3, U38.29
RESET10: C139.1, J11.5, R52.1, S21.3, U42.29
RESET11: C152.1, J12.5, R57.1, S23.3, U46.29
RXI: JP7.3, U6.30
RXI1: JP9.3, U4.30
RXI2: JP22.3, U10.30
RXI3: JP32.3, U14.30
RXI4: JP42.3, U18.30
RXI5: JP52.3, U22.30
RXI6: JP62.3, U26.30
RXI7: JP72.3, U30.30
RXI8: JP82.3, U34.30
RXI9: JP92.3, U38.30
RXI10: JP102.3, U42.30
RXI11: JP112.3, U46.30
SCK: J1.3, R12.1, U6.17
SCK1: J2.3, R5.1, U4.17
SCK2: J3.3, R13.1, U10.17
SCK3: J4.3, R18.1, U14.17
SCK4: J5.3, R23.1, U18.17
SCK5: J6.3, R28.1, U22.17
SCK6: J7.3, R33.1, U26.17
SCK7: J8.3, R38.1, U30.17
SCK8: J9.3, R43.1, U34.17
SCK9: J10.3, R48.1, U38.17
SCK10: J11.3, R53.1, U42.17
SCK11: J12.3, R58.1, U46.17
SCL: R2.1, U1.23, U2.14, U6.28, U$1.1
SCL1: R7.1, U4.28, U7.23, U8.14, U$2.1
SCL2: R15.1, U10.28, U11.23, U12.14, U$5.1
SCL3: R20.1, U14.28, U15.23, U16.14, U$7.1
SCL4: R25.1, U18.28, U19.23, U20.14, U$9.1
SCL5: R30.1, U22.28, U23.23, U24.14, U$11.1
SCL6: R35.1, U26.28, U27.23, U28.14, U$13.1
SCL7: R40.1, U30.28, U31.23, U32.14, U$15.1
SCL8: R45.1, U34.28, U35.23, U36.14, U$17.1
SCL9: R50.1, U38.28, U39.23, U40.14, U$19.1
SCL10: R55.1, U42.28, U43.23, U44.14, U$21.1
SCL11: R60.1, U46.28, U47.23, U48.14, U$23.1
SDA: R1.1, U1.24, U2.13, U6.27, U$1.16
SDA1: R6.1, U4.27, U7.24, U8.13, U$2.16
SDA2: R14.1, U10.27, U11.24, U12.13, U$5.16
SDA3: R19.1, U14.27, U15.24, U16.13, U$7.16
SDA4: R24.1, U18.27, U19.24, U20.13, U$9.16
SDA5: R29.1, U22.27, U23.24, U24.13, U$11.16
SDA6: R34.1, U26.27, U27.24, U28.13, U$13.16
SDA7: R39.1, U30.27, U31.24, U32.13, U$15.16
SDA8: R44.1, U34.27, U35.24, U36.13, U$17.16
SDA9: R49.1, U38.27, U39.24, U40.13, U$19.16
SDA10: R54.1, U42.27, U43.24, U44.13, U$21.16
SDA11: R59.1, U46.27, U47.24, U48.13, U$23.16
TXO: JP7.2, U6.31
TXO1: JP9.2, U4.31
TXO2: JP22.2, U10.31
TXO3: JP32.2, U14.31
TXO4: JP42.2, U18.31
TXO5: JP52.2, U22.31
TXO6: JP62.2, U26.31
TXO7: JP72.2, U30.31
TXO8: JP82.2, U34.31
TXO9: JP92.2, U38.31
TXO10: JP102.2, U42.31
TXO11: JP112.2, U46.31

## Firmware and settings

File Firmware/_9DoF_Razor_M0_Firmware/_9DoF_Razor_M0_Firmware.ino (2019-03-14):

/******************************************************************************
SparkFun 9DoF Razor M0 Example Firmware
Jim Lindblom @ SparkFun Electronics
Original creation date: November 22, 2016
https://github.com/sparkfun/9DOF_Razor_IMU/Firmware

This example firmware for the SparkFun 9DoF Razor IMU M0 
demonstrates how to grab accelerometer, gyroscope, magnetometer,
and quaternion values from the MPU-9250's digital motion processor
(DMP). It prints those values to a serial port and, if a card is
present, an SD card.

Values printed can be configured using the serial port. Settings
can be modified using the included "config.h" file.

Resources:
SparkFun MPU9250-DMP Arduino Library:
  https://github.com/sparkfun/SparkFun_MPU-9250-DMP_Arduino_Library
FlashStorage Arduino Library
  https://github.com/cmaglie/FlashStorage

Development environment specifics:
  Firmware developed using Arduino IDE 1.6.12

Hardware:
  SparkFun 9DoF Razor IMU M0 (SEN-14001)
  https://www.sparkfun.com/products/14001
******************************************************************************/
// MPU-9250 Digital Motion Processing (DMP) Library
#include <SparkFunMPU9250-DMP.h>
// SD Library manages file and hardware control
#include <SD.h>
// config.h manages default logging parameters and can be used
// to adjust specific parameters of the IMU
#include "config.h"
// Flash storage (for nv storage on ATSAMD21)
#ifdef ENABLE_NVRAM_STORAGE
#include <FlashStorage.h>
#endif

MPU9250_DMP imu; // Create an instance of the MPU9250_DMP class

/////////////////////////////
// Logging Control Globals //
/////////////////////////////
// Defaults all set in config.h
bool enableSDLogging = ENABLE_SD_LOGGING;
bool enableSerialLogging = ENABLE_UART_LOGGING;
bool enableTimeLog = ENABLE_TIME_LOG;
bool enableCalculatedValues = ENABLE_CALCULATED_LOG;
bool enableAccel = ENABLE_ACCEL_LOG;
bool enableGyro = ENABLE_GYRO_LOG;
bool enableCompass = ENABLE_MAG_LOG;
bool enableQuat = ENABLE_QUAT_LOG;
bool enableEuler = ENABLE_EULER_LOG;
bool enableHeading = ENABLE_HEADING_LOG;
unsigned short accelFSR = IMU_ACCEL_FSR;
unsigned short gyroFSR = IMU_GYRO_FSR;
unsigned short fifoRate = DMP_SAMPLE_RATE;

/////////////////////
// SD Card Globals //
/////////////////////
bool sdCardPresent = false; // Keeps track of if SD card is plugged in
String logFileName; // Active logging file
String logFileBuffer; // Buffer for logged data. Max is set in config

///////////////////////
// LED Blink Control //
///////////////////////
//bool ledState = false;
uint32_t lastBlink = 0;
void blinkLED()
{
  static bool ledState = false;
  digitalWrite(HW_LED_PIN, ledState);
  ledState = !ledState;
}

#ifdef ENABLE_NVRAM_STORAGE
  ///////////////////////////
  // Flash Storage Globals //
  ///////////////////////////
  // Logging parameters are all stored in non-volatile memory.
  // They should maintain the previously set config value.
  FlashStorage(flashEnableSDLogging, bool);
  FlashStorage(flashFirstRun, bool);
  FlashStorage(flashEnableSD, bool);
  FlashStorage(flashEnableSerialLogging, bool);
  FlashStorage(flashenableTime, bool);
  FlashStorage(flashEnableCalculatedValues, bool);
  FlashStorage(flashEnableAccel, bool);
  FlashStorage(flashEnableGyro, bool);
  FlashStorage(flashEnableCompass, bool);
  FlashStorage(flashEnableQuat, bool);
  FlashStorage(flashEnableEuler, bool);
  FlashStorage(flashEnableHeading, bool);
  FlashStorage(flashAccelFSR, unsigned short);
  FlashStorage(flashGyroFSR, unsigned short);
  FlashStorage(flashLogRate, unsigned short);
#endif

void setup()
{
  // Initialize LED, interrupt input, and serial port.
  // LED defaults to off:
  initHardware(); 
#ifdef ENABLE_NVRAM_STORAGE
  // Load previously-set logging parameters from nvram:
  initLoggingParams();
#endif

  // Initialize the MPU-9250. Should return true on success:
  if ( !initIMU() ) 
  {
    LOG_PORT.println("Error connecting to MPU-9250");
    while (1) ; // Loop forever if we fail to connect
    // LED will remain off in this state.
  }

  // Check for the presence of an SD card, and initialize it:
  if ( initSD() )
  {
    sdCardPresent = true;
    // Get the next, available log file name
    logFileName = nextLogFile(); 
  }

  // For production testing only
  // To catch a "$" and enter testing mode
  Serial1.begin(9600);
}

void loop()
{
  // The loop constantly checks for new serial input:
  if ( LOG_PORT.available() )
  {
    // If new input is available on serial port
    parseSerialInput(LOG_PORT.read()); // parse it
  }

  // Then check IMU for new data, and log it
  if ( !imu.fifoAvailable() ) // If no new data is available
    return;                   // return to the top of the loop

  // Read from the digital motion processor's FIFO
  if ( imu.dmpUpdateFifo() != INV_SUCCESS )
    return; // If that fails (uh, oh), return to top

  // If enabled, read from the compass.
  if ( (enableCompass || enableHeading) && (imu.updateCompass() != INV_SUCCESS) )
    return; // If compass read fails (uh, oh) return to top

  // If logging (to either UART and SD card) is enabled
  if ( enableSerialLogging || enableSDLogging)
    logIMUData(); // Log new data

  // Check for production mode testing message, "$"
  // This will be sent to board from testbed, and should be heard on hadware serial port Serial1
  if ( Serial1.available() )
  {
    if ( Serial1.read() == '$' ) production_testing();
  }
  
}

void logIMUData(void)
{
  String imuLog = ""; // Create a fresh line to log
  if (enableTimeLog) // If time logging is enabled
  {
    imuLog += String(imu.time) + ", "; // Add time to log string
  }
  if (enableAccel) // If accelerometer logging is enabled
  {
    if ( enableCalculatedValues ) // If in calculated mode
    {
      imuLog += String(imu.calcAccel(imu.ax)) + ", ";
      imuLog += String(imu.calcAccel(imu.ay)) + ", ";
      imuLog += String(imu.calcAccel(imu.az)) + ", ";
    }
    else
    {
      imuLog += String(imu.ax) + ", ";
      imuLog += String(imu.ay) + ", ";
      imuLog += String(imu.az) + ", ";
    }
  }
  if (enableGyro) // If gyroscope logging is enabled
  {
    if ( enableCalculatedValues ) // If in calculated mode
    {
      imuLog += String(imu.calcGyro(imu.gx)) + ", ";
      imuLog += String(imu.calcGyro(imu.gy)) + ", ";
      imuLog += String(imu.calcGyro(imu.gz)) + ", ";
    }
    else
    {
      imuLog += String(imu.gx) + ", ";
      imuLog += String(imu.gy) + ", ";
      imuLog += String(imu.gz) + ", ";
    }
  }
  if (enableCompass) // If magnetometer logging is enabled
  {
    if ( enableCalculatedValues ) // If in calculated mode
    {
      imuLog += String(imu.calcMag(imu.mx)) + ", ";
      imuLog += String(imu.calcMag(imu.my)) + ", ";
      imuLog += String(imu.calcMag(imu.mz)) + ", ";    
    }
    else
    {
      imuLog += String(imu.mx) + ", ";
      imuLog += String(imu.my) + ", ";
      imuLog += String(imu.mz) + ", ";
    }
  }
  if (enableQuat) // If quaternion logging is enabled
  {
    if ( enableCalculatedValues )
    {
      imuLog += String(imu.calcQuat(imu.qw), 4) + ", ";
      imuLog += String(imu.calcQuat(imu.qx), 4) + ", ";
      imuLog += String(imu.calcQuat(imu.qy), 4) + ", ";
      imuLog += String(imu.calcQuat(imu.qz), 4) + ", ";
    }
    else
    {
      imuLog += String(imu.qw) + ", ";
      imuLog += String(imu.qx) + ", ";
      imuLog += String(imu.qy) + ", ";
      imuLog += String(imu.qz) + ", ";      
    }
  }
  if (enableEuler) // If Euler-angle logging is enabled
  {
    imu.computeEulerAngles();
    imuLog += String(imu.pitch, 2) + ", ";
    imuLog += String(imu.roll, 2) + ", ";
    imuLog += String(imu.yaw, 2) + ", ";
  }
  if (enableHeading) // If heading logging is enabled
  {
    imuLog += String(imu.computeCompassHeading(), 2) + ", ";
  }
  
  // Remove last comma/space:
  imuLog.remove(imuLog.length() - 2, 2);
  imuLog += "\r\n"; // Add a new line

  if (enableSerialLogging)  // If serial port logging is enabled
    LOG_PORT.print(imuLog); // Print log line to serial port

  // If SD card logging is enabled & a card is plugged in
  if ( sdCardPresent && enableSDLogging)
  {
    // If adding this log line will put us over the buffer length:
    if (imuLog.length() + logFileBuffer.length() >=
        SD_LOG_WRITE_BUFFER_SIZE)
    {
      sdLogString(logFileBuffer); // Log SD buffer
      logFileBuffer = ""; // Clear SD log buffer 
      blinkLED(); // Blink LED every time a new buffer is logged to SD
    }
    // Add new line to SD log buffer
    logFileBuffer += imuLog;
  }
  else
  {
    // Blink LED once every second (if only logging to serial port)
    if ( millis() > lastBlink + UART_BLINK_RATE )
    {
      blinkLED(); 
      lastBlink = millis();
    }
  }
}

void initHardware(void)
{
  // Set up LED pin (active-high, default to off)
  pinMode(HW_LED_PIN, OUTPUT);
  digitalWrite(HW_LED_PIN, LOW);

  // Set up MPU-9250 interrupt input (active-low)
  pinMode(MPU9250_INT_PIN, INPUT_PULLUP);

  // Set up serial log port
  LOG_PORT.begin(SERIAL_BAUD_RATE);
}

bool initIMU(void)
{
  // imu.begin() should return 0 on success. Will initialize
  // I2C bus, and reset MPU-9250 to defaults.
  if (imu.begin() != INV_SUCCESS)
    return false;

  // Set up MPU-9250 interrupt:
  imu.enableInterrupt(); // Enable interrupt output
  imu.setIntLevel(1);    // Set interrupt to active-low
  imu.setIntLatched(1);  // Latch interrupt output

  // Configure sensors:
  // Set gyro full-scale range: options are 250, 500, 1000, or 2000:
  imu.setGyroFSR(gyroFSR);
  // Set accel full-scale range: options are 2, 4, 8, or 16 g 
  imu.setAccelFSR(accelFSR);
  // Set gyro/accel LPF: options are5, 10, 20, 42, 98, 188 Hz
  imu.setLPF(IMU_AG_LPF); 
  // Set gyro/accel sample rate: must be between 4-1000Hz
  // (note: this value will be overridden by the DMP sample rate)
  imu.setSampleRate(IMU_AG_SAMPLE_RATE); 
  // Set compass sample rate: between 4-100Hz
  imu.setCompassSampleRate(IMU_COMPASS_SAMPLE_RATE); 

  // Configure digital motion processor. Use the FIFO to get
  // data from the DMP.
  unsigned short dmpFeatureMask = 0;
  if (ENABLE_GYRO_CALIBRATION)
  {
    // Gyro calibration re-calibrates the gyro after a set amount
    // of no motion detected
    dmpFeatureMask |= DMP_FEATURE_GYRO_CAL;
    dmpFeatureMask |= DMP_FEATURE_SEND_CAL_GYRO;
  }
  else
  {
    // Otherwise add raw gyro readings to the DMP
    dmpFeatureMask |= DMP_FEATURE_SEND_RAW_GYRO;
  }
  // Add accel and quaternion's to the DMP
  dmpFeatureMask |= DMP_FEATURE_SEND_RAW_ACCEL;
  dmpFeatureMask |= DMP_FEATURE_6X_LP_QUAT;

  // Initialize the DMP, and set the FIFO's update rate:
  imu.dmpBegin(dmpFeatureMask, fifoRate);

  return true; // Return success
}

bool initSD(void)
{
  // SD.begin should return true if a valid SD card is present
  if ( !SD.begin(SD_CHIP_SELECT_PIN) )
  {
    return false;
  }

  return true;
}

// Log a string to the SD card
bool sdLogString(String toLog)
{
  // Open the current file name:
  File logFile = SD.open(logFileName, FILE_WRITE);
  
  // If the file will get too big with this new string, create
  // a new one, and open it.
  if (logFile.size() > (SD_MAX_FILE_SIZE - toLog.length()))
  {
    logFileName = nextLogFile();
    logFile = SD.open(logFileName, FILE_WRITE);
  }

  // If the log file opened properly, add the string to it.
  if (logFile)
  {
    logFile.print(toLog);
    logFile.close();

    return true; // Return success
  }

  return false; // Return fail
}

// Find the next available log file. Or return a null string
// if we've reached the maximum file limit.
String nextLogFile(void)
{
  String filename;
  int logIndex = 0;

  for (int i = 0; i < LOG_FILE_INDEX_MAX; i++)
  {
    // Construct a file with PREFIX[Index].SUFFIX
    filename = String(LOG_FILE_PREFIX);
    filename += String(logIndex);
    filename += ".";
    filename += String(LOG_FILE_SUFFIX);
    // If the file name doesn't exist, return it
    if (!SD.exists(filename))
    {
      return filename;
    }
    // Otherwise increment the index, and try again
    logIndex++;
  }

  return "";
}

// Parse serial input, take action if it's a valid character
void parseSerialInput(char c)
{
  unsigned short temp;
  switch (c)
  {
  case PAUSE_LOGGING: // Pause logging on SPACE
    enableSerialLogging = !enableSerialLogging;
#ifdef ENABLE_NVRAM_STORAGE
    flashEnableSerialLogging.write(enableSerialLogging);
#endif
    break;
  case ENABLE_TIME: // Enable time (milliseconds) logging
    enableTimeLog = !enableTimeLog;
#ifdef ENABLE_NVRAM_STORAGE
    flashenableTime.write(enableTimeLog);
#endif
    break;
  case ENABLE_ACCEL: // Enable/disable accelerometer logging
    enableAccel = !enableAccel;
#ifdef ENABLE_NVRAM_STORAGE
    flashEnableAccel.write(enableAccel);
#endif
    break;
  case ENABLE_GYRO: // Enable/disable gyroscope logging
    enableGyro = !enableGyro;
#ifdef ENABLE_NVRAM_STORAGE
    flashEnableGyro.write(enableGyro);
#endif
    break;
  case ENABLE_COMPASS: // Enable/disable magnetometer logging
    enableCompass = !enableCompass;
#ifdef ENABLE_NVRAM_STORAGE
    flashEnableCompass.write(enableCompass);
#endif
    break;
  case ENABLE_CALC: // Enable/disable calculated value logging
    enableCalculatedValues = !enableCalculatedValues;
#ifdef ENABLE_NVRAM_STORAGE
    flashEnableCalculatedValues.write(enableCalculatedValues);
#endif
    break;
  case ENABLE_QUAT: // Enable/disable quaternion logging
    enableQuat = !enableQuat;
#ifdef ENABLE_NVRAM_STORAGE
    flashEnableQuat.write(enableQuat);
#endif
    break;
  case ENABLE_EULER: // Enable/disable Euler angle (roll, pitch, yaw)
    enableEuler = !enableEuler;
#ifdef ENABLE_NVRAM_STORAGE
    flashEnableEuler.write(enableEuler);
#endif
    break;
  case ENABLE_HEADING: // Enable/disable heading output
    enableHeading = !enableHeading;
#ifdef ENABLE_NVRAM_STORAGE
    flashEnableHeading.write(enableHeading);
#endif
    break;
  case SET_LOG_RATE: // Increment the log rate from 1-100Hz (10Hz increments)
    temp = imu.dmpGetFifoRate(); // Get current FIFO rate
    if (temp == 1) // If it's 1Hz, set it to 10Hz
      temp = 10;
    else
      temp += 10; // Otherwise increment by 10
    if (temp > 100)  // If it's greater than 100Hz, reset to 1
      temp = 1;
    imu.dmpSetFifoRate(temp); // Send the new rate
    temp = imu.dmpGetFifoRate(); // Read the updated rate
#ifdef ENABLE_NVRAM_STORAGE
    flashLogRate.write(temp); // Store it in NVM and print new rate
#endif
    LOG_PORT.println("IMU rate set to " + String(temp) + " Hz");
    break;
  case SET_ACCEL_FSR: // Increment accelerometer full-scale range
    temp = imu.getAccelFSR();      // Get current FSR
    if (temp == 2) temp = 4;       // If it's 2, go to 4
    else if (temp == 4) temp = 8;  // If it's 4, go to 8
    else if (temp == 8) temp = 16; // If it's 8, go to 16
    else temp = 2;                 // Otherwise, default to 2
    imu.setAccelFSR(temp); // Set the new FSR
    temp = imu.getAccelFSR(); // Read it to make sure
#ifdef ENABLE_NVRAM_STORAGE
    flashAccelFSR.write(temp); // Update the NVM value, and print
#endif
    LOG_PORT.println("Accel FSR set to +/-" + String(temp) + " g");
    break;
  case SET_GYRO_FSR:// Increment gyroscope full-scale range
    temp = imu.getGyroFSR();           // Get the current FSR
    if (temp == 250) temp = 500;       // If it's 250, set to 500
    else if (temp == 500) temp = 1000; // If it's 500, set to 1000
    else if (temp == 1000) temp = 2000;// If it's 1000, set to 2000
    else temp = 250;                   // Otherwise, default to 250
    imu.setGyroFSR(temp); // Set the new FSR
    temp = imu.getGyroFSR(); // Read it to make sure
#ifdef ENABLE_NVRAM_STORAGE
    flashGyroFSR.write(temp); // Update the NVM value, and print
#endif
    LOG_PORT.println("Gyro FSR set to +/-" + String(temp) + " dps");
    break;
  case ENABLE_SD_LOGGING: // Enable/disable SD card logging
    enableSDLogging = !enableSDLogging;
#ifdef ENABLE_NVRAM_STORAGE
    flashEnableSDLogging.write(enableSDLogging);
#endif
    break;
  default: // If an invalid character, do nothing
    break;
  }
}

#ifdef ENABLE_NVRAM_STORAGE
  // Read from non-volatile memory to get logging parameters
  void initLoggingParams(void)
  {
    // Read from firstRun mem location, should default to 0 on program
    if (flashFirstRun.read() == 0) 
    {
      // If we've got a freshly programmed board, program all of the
      // nvm locations:
      flashEnableSDLogging.write(enableSDLogging);
      flashEnableSerialLogging.write(enableSerialLogging);
      flashenableTime.write(enableTimeLog);
      flashEnableCalculatedValues.write(enableCalculatedValues);
      flashEnableAccel.write(enableAccel);
      flashEnableGyro.write(enableGyro);
      flashEnableCompass.write(enableCompass);
      flashEnableQuat.write(enableQuat);
      flashEnableEuler.write(enableEuler);
      flashEnableHeading.write(enableHeading);
      flashAccelFSR.write(accelFSR);
      flashGyroFSR.write(gyroFSR);
      flashLogRate.write(fifoRate);
      
      flashFirstRun.write(1); // Set the first-run boolean
    }
    else // If values have been previously set:
    {
      // Read from NVM and set the logging parameters:
      enableSDLogging = flashEnableSDLogging.read();
      enableSerialLogging = flashEnableSerialLogging.read();
      enableTimeLog = flashenableTime.read();
      enableCalculatedValues = flashEnableCalculatedValues.read();
      enableAccel = flashEnableAccel.read();
      enableGyro = flashEnableGyro.read();
      enableCompass = flashEnableCompass.read();
      enableQuat = flashEnableQuat.read();
      enableEuler = flashEnableEuler.read();
      enableHeading = flashEnableHeading.read();
      accelFSR = flashAccelFSR.read();
      gyroFSR = flashGyroFSR.read();
      fifoRate = flashLogRate.read();
    }
  }
#endif
  
// All the code and functions below are used for production, and can be removed if desired while still maintaining all product functionality.

// PRODUCTION TESTING VARIABLES
int net_1_pins[] = {11,A0,A2,A4,9};
int net_2_pins[] = {12,10,A1,A3,8};
char input;
int failures = 0;

// PRODUCTION TESTING FUNCTION
void production_testing(void)
{
  digitalWrite(HW_LED_PIN, HIGH); // Turn on Blue STAT LED for visual inspection                       

  while(1) // stay here, until a hard reset happens
  {
    // check for new serial input:
    if ( Serial1.available() )
    {
      // If new input is available on serial1 port
      // These are connected to the RX/TX on Serial2 on the testbed mega2560.
      input = Serial1.read(); // grab it
      switch (input) 
      {
        case '$':
          failures = 0; // reset
          Serial1.print("h"); // "h" for "hello"
          break;
        case '1':
          if(net_1_test() == true) Serial1.print("a");
          else Serial1.print("F");
          break;
        case '2':
          if(net_2_test() == true) 
          {
            Serial1.print("b");
            if(uSD_ping() == true) Serial1.print("c");
            else Serial1.print("F");
          }
          else Serial1.print("F");
          break;        
      }
    }
  }
}


// PRODUCTION TESTING FUNCTION
// Test that the SD card is there and remove log file
// I use the result of the SD.remove() function to know if it deleted the file properly
// Note, this requires that the 9dof wake up and start logging to a new file (even just for a microsecond)
bool uSD_ping(void)
{
//  Serial1.print("nextLogFile: ");
//  Serial1.print( nextLogFile() );

//  Serial1.print("logFileName: ");
//  Serial1.print( String(logFileName) );

  bool remove_log_file_result = SD.remove(logFileName);
//  Serial1.print("r: ");
//  Serial1.print( remove_log_file_result , BIN);

  if(remove_log_file_result == true) return true;
  else
  { 
    return false;
  }
}

// PRODUCTION TESTING FUNCTION
bool net_1_test()
{
  set_nets_all_inputs();
  // check all net 1 is low
  for(int i = 0 ; i <= 4 ; i++)
  {
    bool result;
    result = digitalRead(net_1_pins[i]);
//    Serial1.print(result);
    if(result == true) failures++;
  }   
  Serial1.println(" ");
  // check all net 2 is high
  for(int i = 0 ; i <= 4 ; i++)
  {
    bool result;
    result = digitalRead(net_2_pins[i]);
//    Serial1.print(result);
    if(result == false) failures++;
  }   
  Serial1.println(" ");
  if(failures == 0) return true;
  else return false;
}

// PRODUCTION TESTING FUNCTION
bool net_2_test()
{
  set_nets_all_inputs();
  // check all net 1 is high
  for(int i = 0 ; i <= 4 ; i++)
  {
    bool result;
    result = digitalRead(net_1_pins[i]);
//    Serial1.print(result);
    if(result == false) failures++;
  }   
  //Serial1.println(" ");
  // check all net 2 is low
  for(int i = 0 ; i <= 4 ; i++)
  {
    bool result;
    result = digitalRead(net_2_pins[i]);
//    Serial1.print(result);
    if(result == true) failures++;
  }   
  //Serial1.println(" ");
  if(failures == 0) return true;
  else return false;
}

// PRODUCTION TESTING FUNCTION
void set_nets_all_inputs()
{
  for(int i = 0 ; i <= 4 ; i++)
  {
    pinMode(net_1_pins[i], INPUT);
    pinMode(net_2_pins[i], INPUT);
  }   
}

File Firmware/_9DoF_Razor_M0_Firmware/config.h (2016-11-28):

////////////////////////////////
// Default Logging Parameters //
////////////////////////////////
#define ENABLE_TIME_LOG       true
#define ENABLE_CALCULATED_LOG true
#define ENABLE_ACCEL_LOG      true
#define ENABLE_GYRO_LOG       true
#define ENABLE_MAG_LOG        true
#define ENABLE_QUAT_LOG       false
#define ENABLE_EULER_LOG      false
#define ENABLE_HEADING_LOG    false

////////////////////////////////////////
// Enable Non-Volatile Memory Storage //
////////////////////////////////////////
// If defined, FlashStorage library must be installed
#define ENABLE_NVRAM_STORAGE

////////////////////////
// Serial Port Config //
////////////////////////
#define ENABLE_UART_LOGGING true
// Select the Serial port to log to. Either SERIAL_PORT_USBVIRTUAL
// or LOG_PORT SERIAL_PORT_HARDWARE (SerialUSB or Serial1)
#define LOG_PORT SERIAL_PORT_USBVIRTUAL
#define SERIAL_BAUD_RATE 115200 // Serial port baud

////////////////
// LED Config //
////////////////
#define HW_LED_PIN 13        // LED attached to pin 13
#define UART_BLINK_RATE 1000 // Blink rate when only UART logging

/////////////////////////
// IMU Default Configs //
/////////////////////////
// Note: Some of these params can be overwritten using serial
//  commands. These are just defaults on initial programming
#define DMP_SAMPLE_RATE    100 // Logging/DMP sample rate(4-200 Hz)
#define IMU_COMPASS_SAMPLE_RATE 100 // Compass sample rate (4-100 Hz)
#define IMU_AG_SAMPLE_RATE 100 // Accel/gyro sample rate Must be between 4Hz and 1kHz
#define IMU_GYRO_FSR       2000 // Gyro full-scale range (250, 500, 1000, or 2000)
#define IMU_ACCEL_FSR      2 // Accel full-scale range (2, 4, 8, or 16)
#define IMU_AG_LPF         5 // Accel/Gyro LPF corner frequency (5, 10, 20, 42, 98, or 188 Hz)
#define ENABLE_GYRO_CALIBRATION true

///////////////////////
// SD Logging Config //
///////////////////////
#define ENABLE_SD_LOGGING true // Default SD logging (can be changed via serial menu)
#define LOG_FILE_INDEX_MAX 999 // Max number of "logXXX.txt" files
#define LOG_FILE_PREFIX "log"  // Prefix name for log files
#define LOG_FILE_SUFFIX "txt"  // Suffix name for log files
#define SD_MAX_FILE_SIZE 5000000 // 5MB max file size, increment to next file before surpassing
#define SD_LOG_WRITE_BUFFER_SIZE 1024 // Experimentally tested to produce 100Hz logs

/////////////////////
// Serial Commands //
/////////////////////
#define PAUSE_LOGGING     ' ' // Space - Pause SD/UART logging
#define ENABLE_TIME       't' // Enable/disable time log (milliseconds)
#define ENABLE_ACCEL      'a' // Enable/disable accelerometer log (ax, ay, az)
#define ENABLE_GYRO       'g' // Enable/disable gyroscope log (gx, gy, gz)
#define ENABLE_COMPASS    'm' // Enable/disable magnetometer log (mx, my, mz)
#define ENABLE_CALC       'c' // Enable/disable calculated values
#define ENABLE_QUAT       'q' // Enable/disable quaternion logging (qw, qx, qy, qz)
#define ENABLE_EULER      'e' // Enable/disable estimated euler angles (roll, pitch, yaw)
#define ENABLE_HEADING    'h' // Enable/disable estimated heading logging
#define SET_LOG_RATE      'r' // Adjust logging rate from 1-200 Hz (in 10 Hz increments)
#define SET_ACCEL_FSR     'A' // Set accelerometer FSR (2, 4, 8, 16g)
#define SET_GYRO_FSR      'G' // Set gyroscope FSR (250, 500, 1000, 2000 dps)
#define ENABLE_SD_LOGGING 's' // Enable/disable SD-card logging

//////////////////////////
// Hardware Definitions //
//////////////////////////
// Danger - don't change unless using a different platform
#define MPU9250_INT_PIN 4
#define SD_CHIP_SELECT_PIN 38
#define MPU9250_INT_ACTIVE LOW

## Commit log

2013-08-09 Initial commit of software and hardware files
    Commit includes:
    - V23 hardware files
    - Bootloader hex file
    - Test firmware hex file
    - Combined Hex file used in Production
    v23 Hardware changes:
    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
    [9DOF-Razor-v23.brd, 9DOF-Razor-v23.sch]
2013-08-14 General cleanup in schematic
    Added:
    - Rev code on PCB
    - Minor trace cleanup on mag IC
    Replaced:
    - Net labels with flag style markers
    - Old Frame design with new Frame design that includes CC3.0 and OSHW
    stuff
    [9DOF-Razor-v23.brd, 9DOF-Razor-v23.sch]
2013-08-14 Changed all Y junctions to T junctions
    On PCB: all traces with Y junctions are now T junctions.
    [9DOF-Razor-v23.brd]
2013-09-17 Created Panel
    Normal sized panel with rails
    [9DOF-Razor-Panel-v23.brd]
2016-08-01 Standardizing file names.
    [sparkfun-9dof-razor-imu.brd, sparkfun-9dof-razor-imu.sch]
2016-08-01 Initial commit of v24.
    [sparkfun-9dof-razor-imu.brd, sparkfun-9dof-razor-imu.sch]
2016-08-01 Schematic cleanup, bottom re-routing.
    [sparkfun-9dof-razor-imu.brd, sparkfun-9dof-razor-imu.sch]
2016-08-01 Cleaning up routing.
    [sparkfun-9dof-razor-imu.brd]
2016-08-02 Brd/sch tweaks after engineer checklist.
    [sparkfun-9dof-razor-imu.brd, sparkfun-9dof-razor-imu.sch]
2016-08-08 Reorganizing expansion header(s), layout cleanup, PROD_ID's.
    [sparkfun-9dof-razor-imu.brd, sparkfun-9dof-razor-imu.sch]
2016-08-08 Adding labels to bottom side.
    [sparkfun-9dof-razor-imu.brd]
2016-09-12 Updating version number to redboard release - v30
    [sparkfun-9dof-razor-imu.brd, sparkfun-9dof-razor-imu.sch]
2016-09-19 Post-review changes - swapping 3.3V and GND, moving switch in.
    [sparkfun-9dof-razor-imu.brd, sparkfun-9dof-razor-imu.sch]
2016-09-19 Checklist adjustments - mostly silkscreen nudging.
    [sparkfun-9dof-razor-imu.brd, sparkfun-9dof-razor-imu.sch]
2016-11-16 Adding bootload pin support to bootloader.
2016-11-22 Initial commit of 9DoF Razor IMU M0 example firmware.
2016-11-22 Updating default and max frequency to 100Hz
2016-11-28 Fixing return value from initSD
    [_9DoF_Razor_M0_Firmware.ino]
2016-12-01 Squashed 'Libraries/Arduino/' content from commit 3370a18
    git-subtree-dir: Libraries/Arduino
    git-subtree-split: 3370a188e7f8007900c323672a89cbfaf47e1299
2016-12-12 Value Added to .brd File
    Right Angle Slide Switch Added for 3D Modeling
    [sparkfun-9dof-razor-imu.brd, sparkfun-9dof-razor-imu.sch]
2019-03-14 Update gyro calibration implementation
    *dmp_enable_feature* (**DMP_FEATURE_GYRO_CAL**) needs to be called in conjunction with **DMP_FEATURE_SEND_CAL_GYRO**
    See: https://github.com/sparkfun/9DOF_Razor_IMU/blob/master/Libraries/Arduino/src/util/inv_mpu_dmp_motion_driver.c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
    Brought up by in this issue: https://github.com/sparkfun/9DOF_Razor_IMU/issues/10
    Tested to work.
    [_9DoF_Razor_M0_Firmware.ino]

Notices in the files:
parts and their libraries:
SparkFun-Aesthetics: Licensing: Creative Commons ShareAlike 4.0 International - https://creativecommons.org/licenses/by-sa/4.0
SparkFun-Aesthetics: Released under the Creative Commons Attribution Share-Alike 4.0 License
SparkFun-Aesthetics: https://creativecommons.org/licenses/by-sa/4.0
